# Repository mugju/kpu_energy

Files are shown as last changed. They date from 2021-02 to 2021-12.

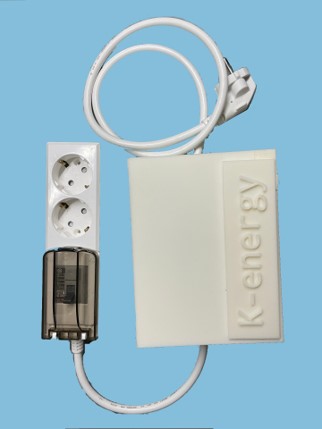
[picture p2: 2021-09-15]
Hardware/smplug.jpg

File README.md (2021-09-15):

<h1>kpu_energy</h1>
<h3>참여자 : 김동혁, 김영민, 김재현, 이영채</h3>

<h2>무엇을 위한 시스템인가요? </h2>
본 시스템은 매장 내 전자기기의 전력사용량을 모니터링하며,<br>카메라를 통한 모션인식/얼굴인식을 통해 매장 손님수를 파악하고,
<br>손님이 없을 경우 전자기기의 전원을 차단 및 출력을 조정하여 에너지 절약을 실현합니다

<h2>사용한 기술/기기 은(는) 무엇인가요?</h2>

<h2>-HW-</h2>
NodeMCU , Raspberry Pi , SCT-013 , Ir sensor ..etc<br><br>

  

<h2>-SW-</h2>
<h3>App</h3> 
<h4>Flutter</h4>




<h4>Windows Client in Pos</h4> <br>

Swing Java javafx



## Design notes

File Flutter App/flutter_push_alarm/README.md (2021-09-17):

# flutter_push_alarm

A new Flutter project.

## Getting Started

This project is a starting point for a Flutter application.

A few resources to get you started if this is your first Flutter project:

- [Lab: Write your first Flutter app](https://flutter.dev/docs/get-started/codelab)
- [Cookbook: Useful Flutter samples](https://flutter.dev/docs/cookbook)

For help getting started with Flutter, view our
[online documentation](https://flutter.dev/docs), which offers tutorials,
samples, guidance on mobile development, and a full API reference.

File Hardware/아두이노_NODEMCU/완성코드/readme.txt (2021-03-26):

오후 9:26 2021-03-26
현재 스마트 플러그 완성된 상태이며 , 웹서버와의 연동만 이루어지면 됨.

배전반 허브의 경우 현재 IR송수신 가능하며 라즈베리파이와의 연동 실험중
소스코드는 추후 추가할 예정임

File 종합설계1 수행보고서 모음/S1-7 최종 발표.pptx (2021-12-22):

## 컴퓨터 공학부 SW 캡스톤 디자인

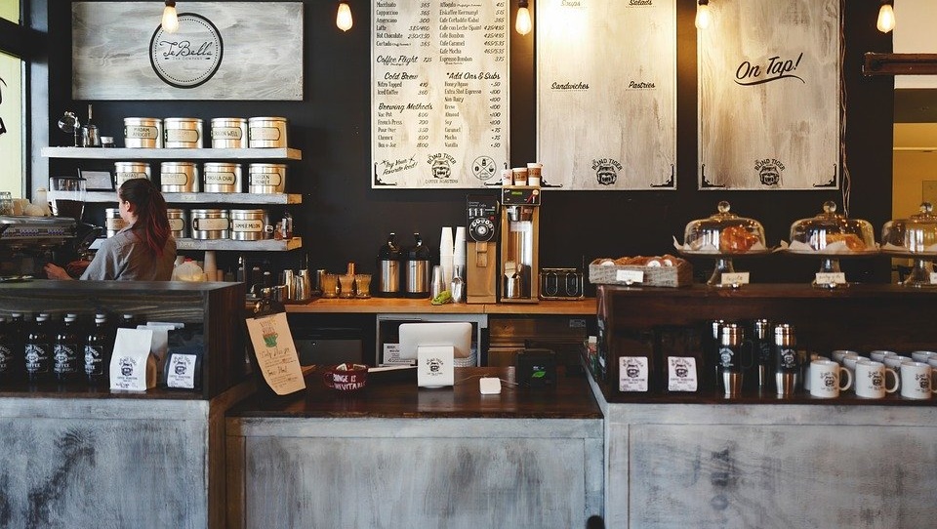
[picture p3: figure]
다방, 술집, 가게, 카페, 에스프레소, 기계, 컵, 사업, 빛, 구근, 벽, 메뉴, 보드
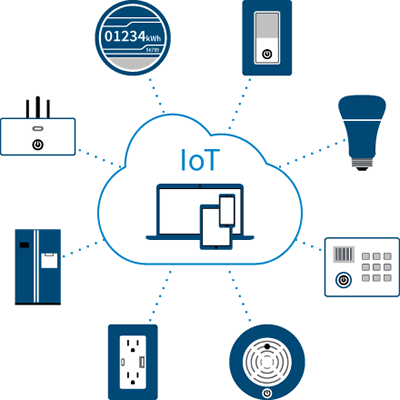
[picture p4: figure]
IoT, 스마트 홈 및 빌딩 자동화 | Power Integrations, Inc.

S1 – 7 IoT기반 에너지 매니저 시스템
기업 연계형 – Net-KTI

발표자 : 2016156003 김동혁 소프트웨어전공

지도교수 : 김영곤 교수님

팀장 : 김영민 (소프트웨어 전공) 2016156007
팀원 : 김동혁 (소프트웨어 전공) 2016156003
김재현 (소프트웨어 전공) 2016156009
이영채 (소프트웨어 전공) 2016156022

## 목차

1 작품 소개

1-1 목적
1-2 구성도

4 시연영상

2 H/W 소개

2-1 스마트 플러그 구성 / 기능
2-2 배전반 측정기 구성 / 기능
2-3 허브 구성 / 기능

3 S/W 소개

3-1 android Application
3-2 Windows app for Pos

## 작품 소개

Chapter 1

## 작품의 목적

1-1

1 개발 배경

- NetKTI와의 연계로 주제 선정
- 장시간 사용하지않는 전력기구의 대기전력제어
- 손님 유무에 따라 에너지를 제어할 수 있는 IoT 환경구성

2 작품의 목표

“매장 내 전자제품을
모니터링 및 제어할 수 있는
에너지 매니지먼트 시스템 ”

4

## 구성도

1-2

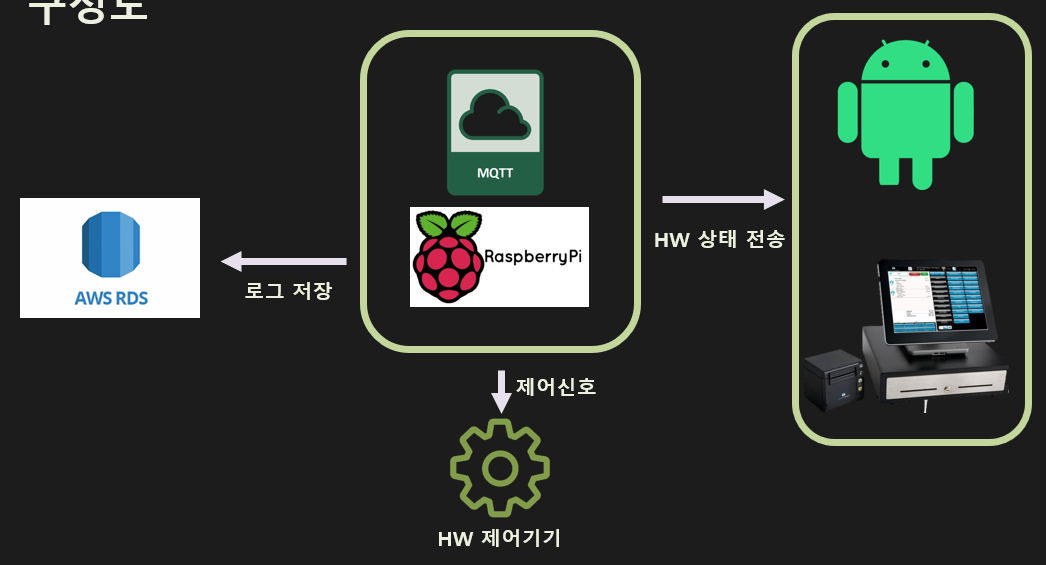
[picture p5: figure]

5

## H/W 소개

Chapter 2

## 스마트 플러그

2-1

1 스마트 플러그 전체모습

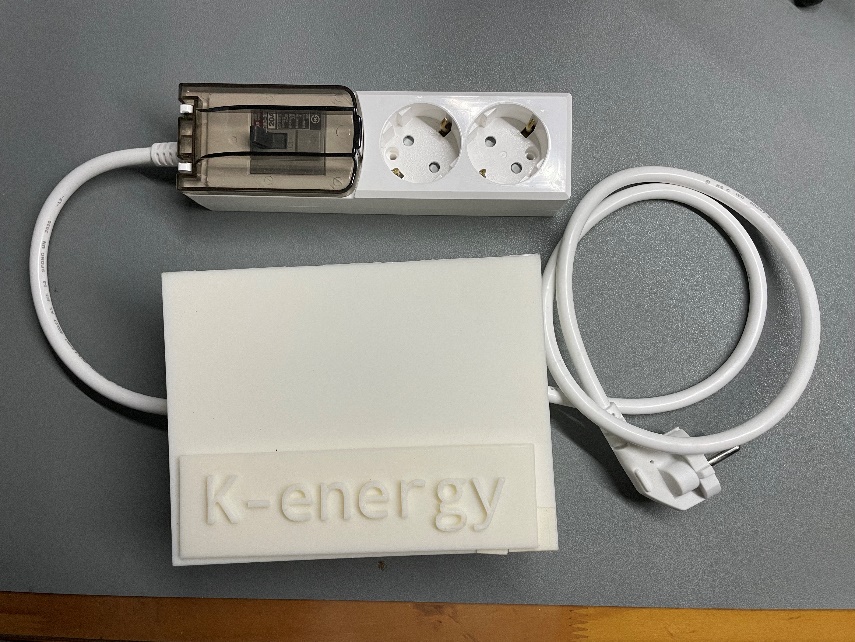
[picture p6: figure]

본문 요약

- 상세항목의 내용
- 상세항목의 내용

2 내부 구성

와이파이 MCU보드
멀티플러그
전류센서
10A 릴레이 .. etc

3 기능

사용전력 모니터링
릴레이를 통한 원격 전원 차단기능
사용 전력과 전원 on/off로그를 DB에 저장

7

## 배전반 측정기

2-2

1 배전반 측정기 전체모습

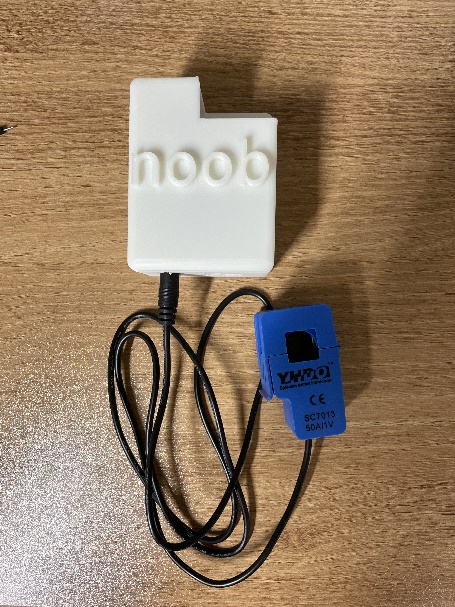
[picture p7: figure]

3 기능

사용전력 모니터링

플러그를 사용할 수 없는 기기의 전력측정을 위함
Ex) 에어컨 , 간판 (3500W 이상 혹은 지리적위치)

본문 요약

- 상세항목의 내용
- 상세항목의 내용

2 내부 구성

와이파이 MCU보드
SCT-013 (전류측정 센서)

4 특징

8

## 허브

2-3

1 허브전체모습

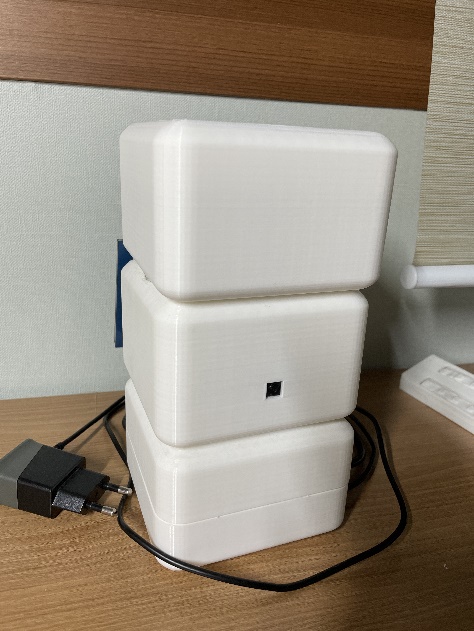
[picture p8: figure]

본문 요약

- 상세항목의 내용
- 상세항목의 내용

3 기능

HW에 제어신호를 보내는 MQTT 서버 역할 수행
모니터링 값을 사용자에게 보내주는 서버
카메라를 통한 매장 내 손님 수 파악

프라이버시를 위한 녹화기능 X
얼굴인식과 모션인식을 합하여 보다 정확한 재실인원 파악기능
외부서버가 아닌 홈 네트워크 속에서 서버를 운영하기에 속도가 빠름

2 내부 구성

라즈베리파이 3B+
5MP 카메라
Lcd모니터
LED 인디케이터
와이파이 MCU보드

4 특징

9

## S/W 소개

Chapter 3

## Android Application

3-1

1 어플리케이션 메인 스크린샷

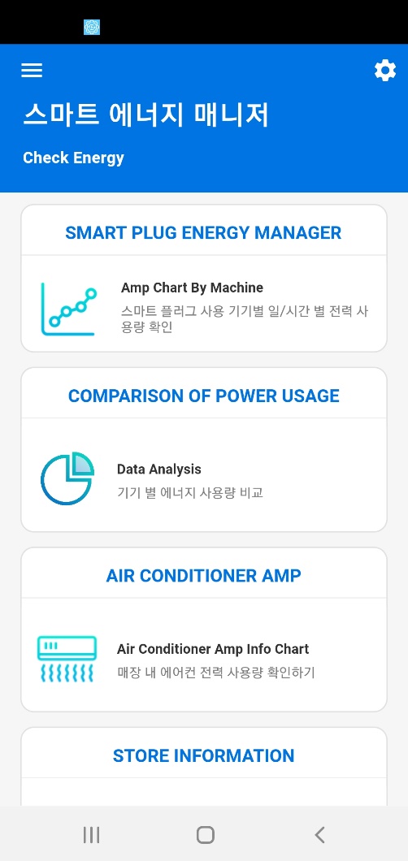
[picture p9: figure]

2 주요 기능

Smart Plug Energy Manager
→ 스마트 플러그 순간전력데이터를 zoom-in/zoom-out 그래프로 출력함

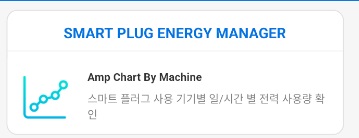
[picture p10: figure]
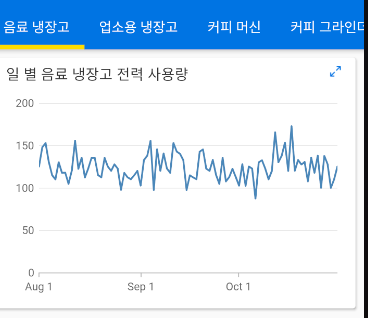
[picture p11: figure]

11

## Android Application

3-1

2 주요 기능

Comparison Of Power User
→ 해당 데이터로 다양한 각도에서 그래프 정보 출력
→ 기기 별 에너지 사용량 비교 그래프 출력

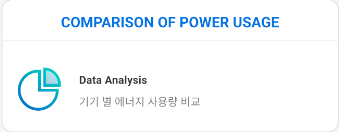
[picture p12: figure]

기기원격제어
- smart plug 제어 가능
- 스마트 플러그 on/off시 푸시 알림 수신
- 재실 인원 유무 파악
- 스마트플러그, 배전반 순간/누적 전력 표시

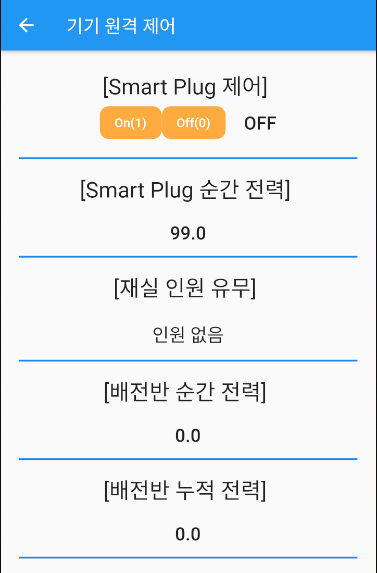
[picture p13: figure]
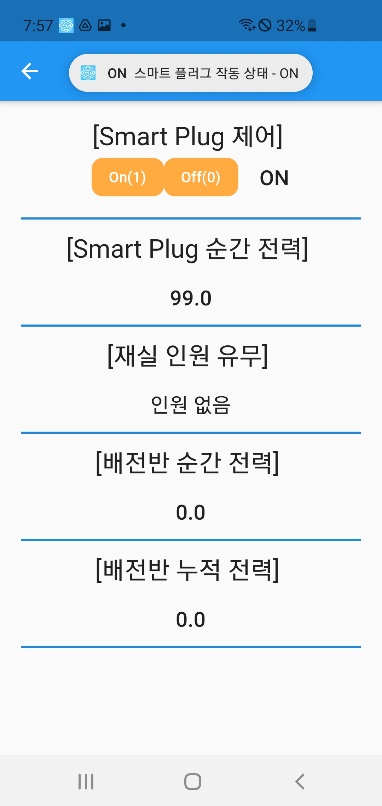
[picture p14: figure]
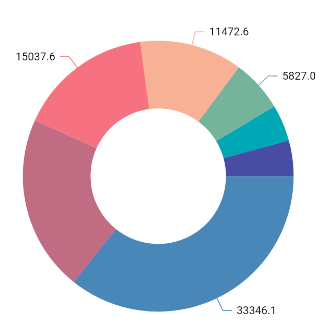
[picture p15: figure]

12

## Client program in Pos

3-2

1 클라이언트 프로그램 스크린샷

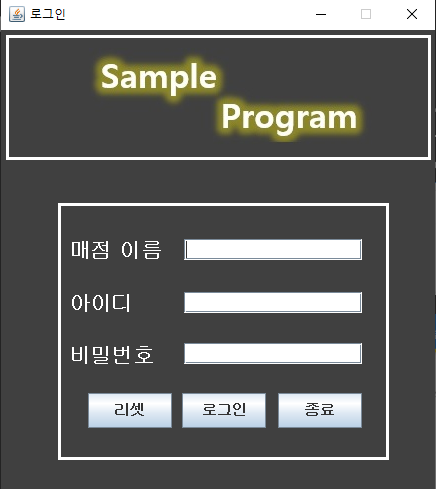
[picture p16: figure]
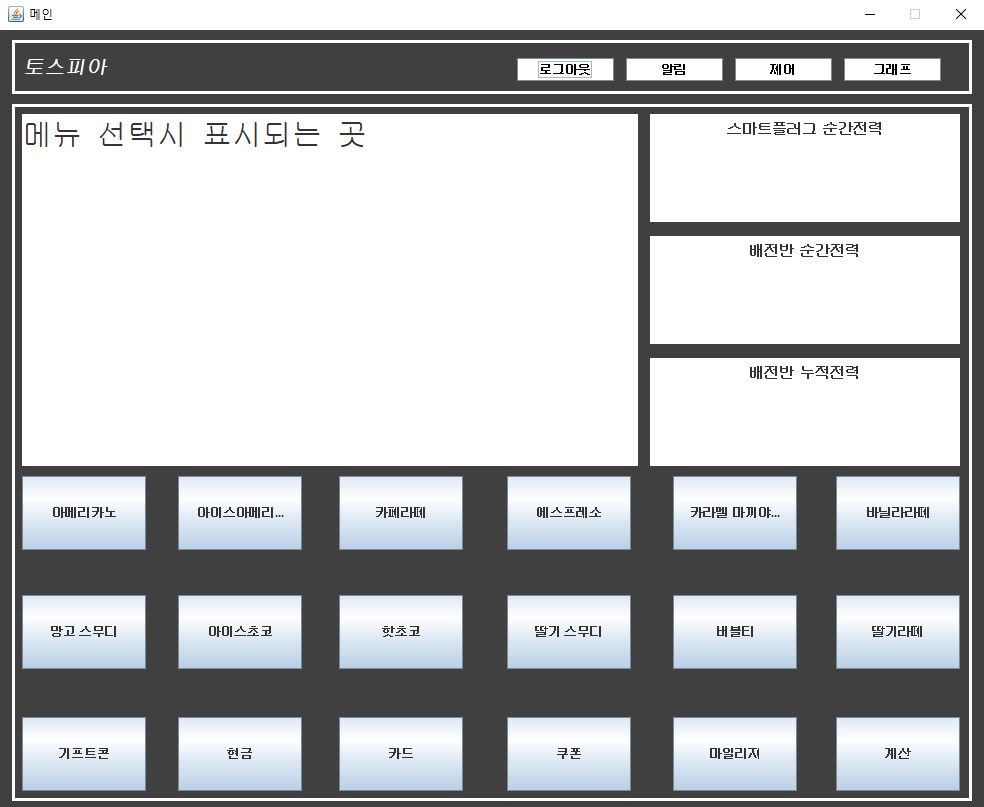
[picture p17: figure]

13

## Client program in Pos

3-2

2 기능

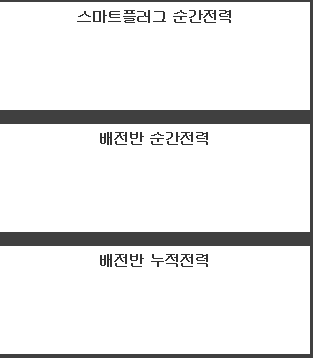
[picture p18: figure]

전력값 출력
→ 스마트 플러그와 배전반에서 측정한 순간 전력과 누적전력을 화면에 실시간으로 출력

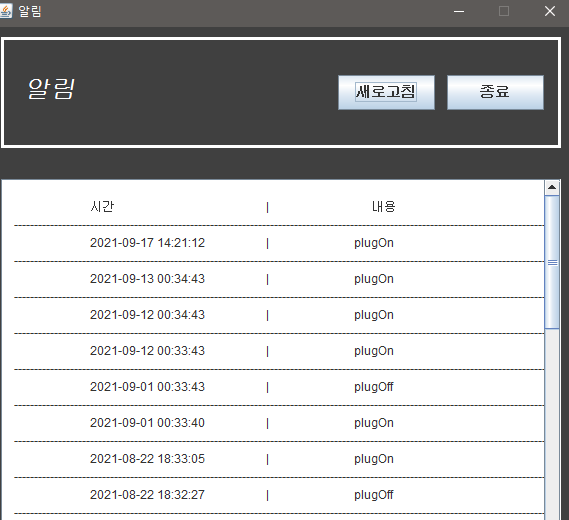
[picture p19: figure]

전원 기록 알림
→ 프로그램이 종료되어 있을 때 푸시 알림을 받을 수 없으므로 DB에 저장된 스마트 플러그의 활동을 보여줌

14

## Client program in Pos

3-2

2 기능

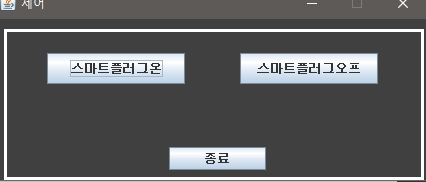
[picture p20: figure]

기기원격제어
- 스마트 플러그 제어 가능
- 원격제어시 팝업을 통한 알림

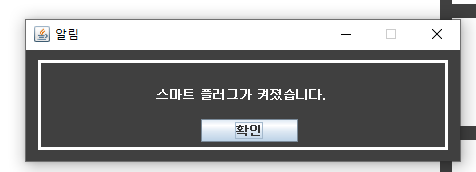
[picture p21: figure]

그래프 출력
- 제품별, 시간/일/월을 기준으로 전력 사용량을 그래프로 표현

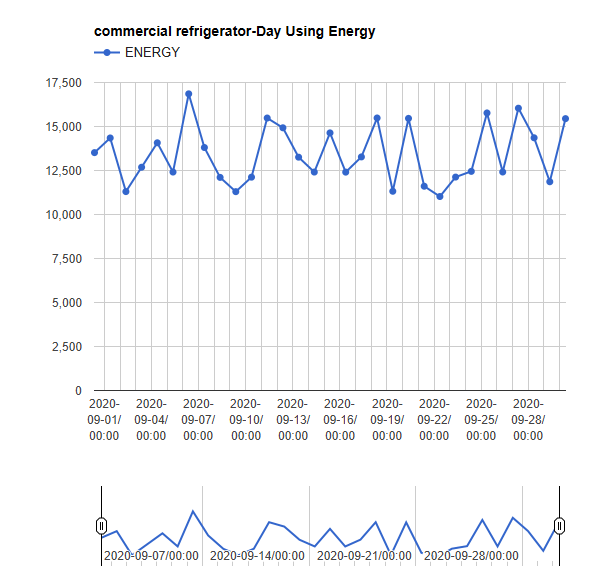
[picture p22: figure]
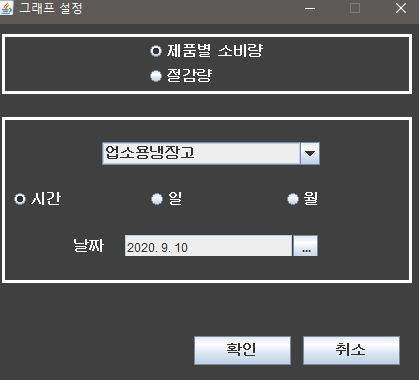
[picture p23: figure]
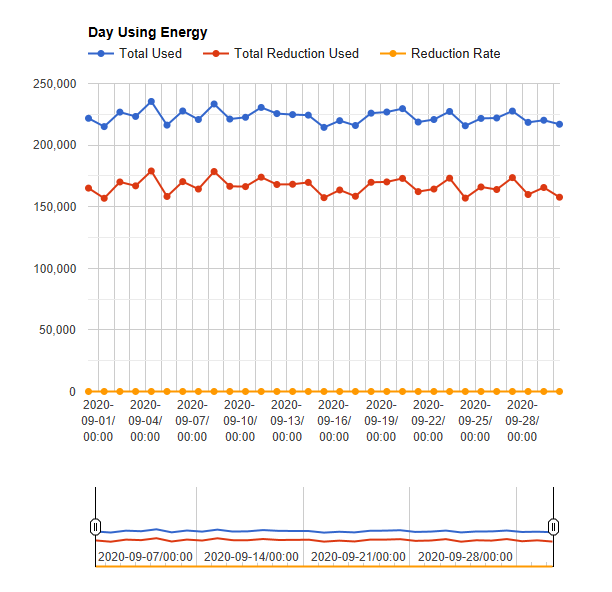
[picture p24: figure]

15

## 시연 영상

Chapter 4

## 감사합니다.

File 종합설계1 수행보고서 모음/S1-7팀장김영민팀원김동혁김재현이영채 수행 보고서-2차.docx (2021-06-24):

종합설계 프로젝트 수행 보고

프로젝트명 | IoT기반 에너지 매니저시스템
팀번호 | S1-7
문서제목 | 수행계획서( O ) 2차발표 중간보고서( ) 3차발표 중간보고서( ) 최종결과보고서( )

기업연계 : Net-KTI

2021.03.08

팀원 : 김영민(팀장)

김동혁

김재현

이영채

지도교수 : 김영곤 교수님 (인)

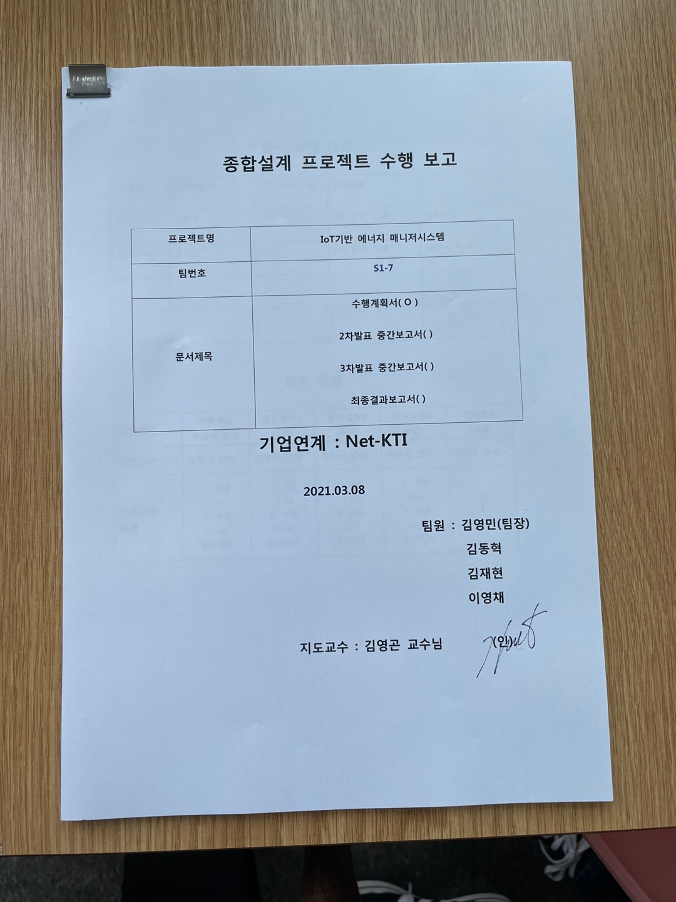
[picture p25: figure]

문서 수정 내역

작성일 | 대표작성자 | 버전(Revision) | 수정내용
2021.2.14 | 김동혁 | 1.0 | 1차 발표 자료 | 최초작성
2021.03.01 | 김영민 | 2.0 | 2차 발표 자료 | 설계서 추가

문서 구성

진행단계 | 프로젝트 계획서 발표 | 중간발표1 (3월) | 중간발표2 (5월) | 학기말발표 (6월) | 최종발표 (10월)
기본양식 | 계획서 양식 | 계획서 양식 | 계획서 양식 | 계획서 양식 | 계획서 양식
포함되는 내용 | Ⅰ. 서론 (1~6) Ⅱ. 본론 (1~3) 참고자료 | Ⅰ. 서론 (1~6) Ⅱ. 본론 (1~4) 참고자료 | Ⅰ. 서론 (1~6) Ⅱ. 본론 (1~5) 참고자료 | Ⅰ. 서론 (1~6) Ⅱ. 본론 (1~7) 참고자료 | I II III

이 문서는 한국산업기술대학교 컴퓨터공학부의

“종합설계”교과목에서 프로젝트

“IoT기반 에너지 매니저시스템”을 수행하는

(S1-7, 김영민,김재현,김동혁,이영채)들이 작성한 것으로 사용하기 위해서는 팀원들의 허락이 필요합니다.

기업 질문사항 및 답변

기업 담당자: 김태형

질문 번호 | PPT page | 질문내용 | 팀에서 고려사항 | 답변
1 | 3p | 주제의 적용을 매장으로 선택하고 진행하고 있는데 실제로 사용되고 있는 공간이 있는지? 있다면 어떤 공간인지 알려주실 수 있나요 | 저희 팀에서는 학교 내 에 있는 맘스터치와 같은 프랜차이즈 매장에 도입하는 것을 생각하고 있습니다. | 인건비 부담으로 인해 무인화가 트렌드가 되어 카페 / 무인독서실 / 대형 프랜차이즈 등 다수의 업종에 적용되어 있습니다.
2 | | 이런 시스템을 적용시킬 수 있는 장소 (1번에서 고려해주신 장소)의 샘플데이터를 받을 수 있나요? (전력, 온도 등등..) | 일단 저희가 전력데이터를 수집하기위해 접촉/ 비접촉 전류센서를 사용하고 있고, 온 습도, 모션인식을 통해 손님수를 측정하는데 더 고려할 요소가 있는지 궁금합니다. | 샘플 데이터는 보안 및 개인정보문제로 외부 변환이 안되어 제공이 어렵습니다. 재실감지 센서라고 레이더센서/마이크로파 등을 이용하여 입출입 인원 파악이 가능한 센서가 있으니 찾아보시기 바랍니다.
3 | | 전력수집 및 제어 대상으로 혹시 저희가 설정한 것 이외에 더 추가할 만한 것을 추천해 주실 수 있을까요? | 저희가 고려한 바는 냉난방기구, 조명, 스크린 정도를 고려하고 있는데 | 온도센서 / 스마트플러그를 활용하면 온냉장 시설의 항온 유지 기능이 구현 가능합니다. (수족관 등 온도변화에 민감한 동식물 관리) - 산소포화도 센서 및 발생기를 추가하여 일정한 환경 구성 가능

표 1

# 1. 서론

주요 내용 | 1-1. 작품선정 배경 및 기존 기술 분석 1-2. 프로젝트 개발 목표 1-3. 팀 역할 분담 1-4. 개발 일정 1-5. 개발 환경

## 1-1. 작품선정 배경 및 기존 기술 분석

1) 작품선정 배경

-에너지를 효율적으로 관리하기 위한 시스템의 필요

-한창 떠오르는 4차 산업혁명의 기술 적용에 적합

이에 따라 기존 유사 기술들을 분석한 결과,

관련 연구 및 사례 | 개선점
스마트빌딩 통합관리·E절감솔루션 | - 관련 전문 지식을 보유하지 않은 일반 사용자도 이용하기 편하도록 인터페이스를 구현
오 파워 | - IoT를 사용하여 에너지 장치 각각의 데이터를 수집하고 제어한다.
글로벌 스마트시티(스마트 매장 에너지 관리) | - 실내 온도, 밀집도와 같은 환경 요소들도 파악하여 서비스 제공 - 빅데이터를 사용하여 적절한 에너지 사용 방법 알림

와 같은 개선점을 찾을 수 있었음.

이에 따른 구체적 해결방안으로

에너지 사용량을 파악하기 위해 에너지 사용량을 시각화 해야함.

- 사용량을 그래프를 사용하여 사용자가 알아보기 쉽게 제공.

- 지정한 사용량 초과 및 비정상적인 사용량 인식 시에 사용자에게 알림 제공

각 에너지 사용량을 측정하는 센서 데이터들을 모아 딥러닝을 통해 자동적인 관리 시스템을 구축한다.

- 각 요인에 따라 자동적으로 기기들을 제어하고, 수동적인 제어 역시 스마트폰이나, PC로 제어 가능하다.

- 제어된 로그들은 사용자에게 앱이나 웹의 형태로 제공된다.

## 1-2 프로젝트 개발 목표

1) 연구 및 개발 목표

IoT를 사용하여 다양한 에너지 사용량을 측정하고, 측정된 데이터를 빅데이터를 통해 분석하여 에너지를 효율적으로 사용하도록 사용자에게 알맞은 사용방법을 추천할 수 있도록 한다. 또한 인공지능에 의해 각종 에너지를 통제하고 사용자가 원격으로도 제어가 가능하도록 한다.

2) 기능정의
- 사용자에게 에너지 사용량을 시각화하여 보여준다.
- 에너지 소비 솔루션을 인공지능을 통해 제공한다.
- 에너지 소비 피크 시간에 대한 정보를 인공지능을 통해 분석하여 제공한다.
- 절감 효과에 대한 결과 데이터를 제공한다.
- 에너지는 전기, 온도로 정의한다.
- 사용량에 대한 기준을 정하고, 초과했을 때 알림 기능을 제공한다.
- 웹으로 모니터링 시스템을 제공한다.
- 모든 에너지는 스마트폰 어플리케이션을 통해 제어가 가능하다.
- 에너지 소비에 대한 제어는 인공지능과 사용자에 의해 제어된다.
- 날씨, 유동인구, 시간 데이터에 대한 정보를 사용하여 데이터를 분석한다.
- 에너지 데이터는 외부 서버 데이터베이스에 저장된다.
- 음성 인식을 통해 제어가 가능하도록 한다.

## 1-3 팀 역할 분담

| 김재현 | 이영채 | 김영민 | 김동혁
자료수집 | - HTML, JSP - Android Studio | - AWS RDS - 영상 처리 | - Google colab - 머신 러닝 모델 | - 라즈베리파이 - Atmega, 센서
설 계 | - 정보 웹 페이지 - 앱 | - 데이터 베이스 설계 - 모션 인식 개발 | - 머신 러닝 모델 적용 | - 라즈베리파이와 Atmega 연동
구 현 | - 웹페이지에 정보 표시 - 앱으로도 호환 | - 데이터 베이스 구축하여 데이터 관리 - 카메라를 이용한 모션 인식 | - 머신 러닝을 통해 결과 예측 | - 라즈베리파이에서 수집한 데이터 전송 - Atmega를 이용한 데이터 수집
테스트 | - 머신 러닝 - 예측 결과 - 웹 페이지, 앱 연동 - 라즈베리파이, Atmega 연동 및 데이터 수집

## 1-4 개발 일정

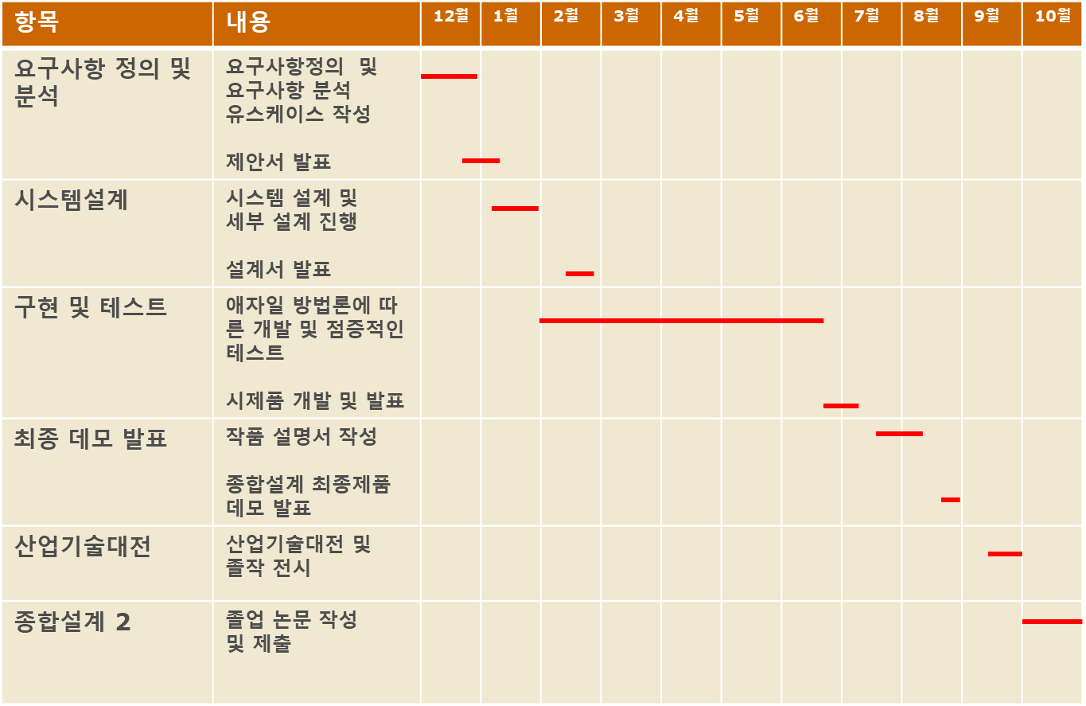
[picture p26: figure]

## 1-5 개발 환경

스마트 플러그 | NODEMCU | Esp8266 탑재. 인터넷 접속과 데이터 수집을 수행
| ACS-712 | 교류전류데이터 수집
| DHT-22 | 온습도 측정
| 5V relay | 5v 구동 릴레이, 전자기기 전원제어
| AC-DC컨버터 | 교류전원을 사용하여 보드, 센서를 구동

허브 | Arduino uno | 센서데이터 수집용(analog)
| SCT-013 | 비접촉 전류센서 (배전반 사용)
| Raspberry 3b+ | 영상처리, 아두이노 전원제공, 인터넷 접속
| Pi camera | 손님인식용 카메라
| 적외선 송,수신 센서 | 리모콘의 신호를 복제하여 기기제어

S/W | 서버 | Apache Tomcat 9.0 / Ubuntu 18.0.4 LTS
| DB | RDS for MySQL 8.0
| 머신 러닝 | Google Colaboratory
| 시각화 | Grafana
| 모션 인식 | OpenCV

# 2. 본론

주요 내용 | 2-1. 개발 내용 1) 환경 데이터 수집 2) 스마트 플러그 3) 제어 허브(배전반 측정용) 4) 머신 러닝 5) 웹 6) 데이터 베이스 2-2. 문제 및 해결 방안 2-3. 수행 시나리오 1) 구성도 2) 데이터 수집 시나리오 3) 데이터 저장 & 머신 러닝 시나리오 4) 사용자 인터페이스 시나리오 5) 제어 시나리오 2-4. 상세 설계 1) 유스케이스 다이어그램 2) 클래스 다이어그램 2-1) Display 2-2) MachineLearning 2-3) Sensor 1) PeopleRecogSensor 2) ampSensor 3) DHTSensor 2-4) Control 1) IRControl 1-1) AirControl 1-2) MonitorControl 2) PlugControl 3) GUI 화면 설계 3-1) 로그인 화면 3-2) 메인 화면(전체 모니터링) 3-3) 실시간 기상데이터 3-4) 사용비율 비교 3-5) 에너지 사용 예측 3-6) 기간별 사용량 3-7) 에너지 제어 3-8) 문의

## 2-1. 개발 내용

1) 환경 데이터 수집


2) 스마트 플러그


3) 제어 허브 (배전반 측정용)


4) 머신 러닝


5) 웹


6) 데이터 베이스


## 2-2 문제 및 해결 방안

문제 | 시스템을 사용하기 위한 인터페이스는 어떻게 구현할 것인가
해결 방안 | 스프링 프레임워크를 이용하여 웹을 구현하고 Apache Tomcat을 이용해 서버를 운영한다. 웹은 사용자에게 실제 에너지 사용량, 예상 에너지 사용량, 에너지 절감량, 기기 제어 등의 기능을 제공한다.

문제 | 전력데이터를 어떻게 수집할 것인가?
해결 방안 | 전력을 바로 구할수 있는 센서는 존재하지 않았고 전류센서로 전압을 곱해 전력을 구할 수밖에 없었다. 다만 여기서 일반적인 전류센서의 경우 접촉 방식으로 전선을 단선하여 측정하는 방식이었는데 저 전류의 경우 크게 위험하지않지만 에어컨이나 높은 전류가 흐르는 제품의 경우 단선하여 연결하는데에 큰 부담이 되었다. 이에따라 조사중 비접촉 전류센서인 SCT 013 제품을 찾아 배전반에 매설하는 방식으로 전력을 측정하도록 하였다.

문제 | 제품을 어떻게 제어할 것인가?
해결 방안 | 단순한 제품들이라면 그저 전원을 끊고 연결하기만하면 충분하지만 전선이 직접적으로 연결되어있지않은 즉, 비접촉 전류센서를 이용하는 제품의 경우 제어가 어려웠다. 에어컨이 가장 큰 경우였는데 고민중 IR(적외선) 신호를 이용해 기존 리모콘의 적외선 신호를 복제하여 원거리에서 풍량, 온도등을 제어하는 방법을 고안했다. 이 방법은 단순하게 에어컨 뿐만 아니라 전선이 매설되어있는 전자기기 (프로젝터등) 과 같은 기기의 제어에도 효과적일 것이라 생각한다.

문제 | 사람 인식을 함에 있어, 정면 외의 모습은 인식이 불가한 문제를 어떻게 해결할 것인가?
해결 방안 | 사람의 뒷 모습이나 옆 모습, 앉아있는 모습까지 학습시키는 것에 무리가 있다고 판단하여 움직임을 감지하는 방법으로 변경하기로 했다. 데이터베이스에 전송할 때는 5분 내에 움직임이 감지되면 1을 전송하여주고, 이외에는 0을 전송하도록 했다.

문제 | 머신러닝을 어떤 분야에 적용할 것인가?
해결 방안 | 초기에 대략적인 구상으로만 머신러닝을 해당 졸업 작품에 접목하여 적용 범위가 불명확했었다. 팀원들과 충분히 토의한 결과 수집한 데이터를 통해 미래의 전력 사용량을 예측하는 분야에서 머신러닝을 접목시킬 수 있다고 결론을 도출하였다. 현재 딥러닝 모델중 LSTM 모델과 Facebook에서 개발한 Prophet 모델을 사용 모델로 고려중으고, 현재 수집 중인 데이터에 대해 더 효율적인 모델을 찾기 위해 노력하겠다.

## 2-3 수행 시나리오

1) 구성도


2) 데이터 수집 시나리오
      1. 매장 내 전력사용량을 전류센서를 통해 수집한다.


      2. 매장 내 실내온습도를 DHT22 센서를 통해 수집한다.
      3. 매장 내 카메라를 이용하여 매장내 손님수를 분석하여 라즈베리파이에 유선으로 저장한다.
3) 시스템 수행 시나리오 – 데이터 저장 & 머신러닝


1. 라즈베리파이에서 센서데이터를 데이터베이스로wifi를 통해 전송한다.
2. 데이터베이스에서는 구글 클라우드로 데이터를 제공해준다.
3. 기상청으로부터 외부 날씨 데이터를 API를 통해 받아온다.
4. 수집한 데이터들을 통한 머신러닝을 통해 예측전력값을 구한다.
5. 예측데이터를 데이터 베이스에 저장한다.
4) 시스템 수행 시나리오 – 사용자 인터페이스


      1. 데이터베이스에 저장된 데이터를 시각화하여 웹서버로 전송한다.
      2. 웹서버는 사용자에게 인터페이스를 제공한다.
5) 시스템 수행 시나리오 – 제어


      1. 사용자 인터페이스에서 제어명령을 내린다.
      2. 해당 명령은 웹서버를 거쳐 원격제어 모듈로 전송된다.
      3. IR신호, 및 릴레이를 사용하여 전열기구, 전등, 플러그, 모니터 등을 제어한다.

## 2-4 상세 설계

1) 유스케이스 다이어그램


2) 클래스 다이어그램


2-1) Display

설명 | 웹에서 데이터 베이스의 정보를 이용하여 시간별 예측 전력 사용량, 현재 전력 사용량, 기기를 제어해 절감된 전력량을 시각화하여 사용자한테 제공한다.
메서드 | public showChart(self, object):void | 데이터를 시각화하여 사용자한테 제공한다.
| public getData(String,datetime) : object | 데이터 베이스에서 현재 사용중인 데이터를 가져온다.
| public getPredictData(String): float[][] | 데이터 베이스에서 머신러닝을 통해 구한 예측 전력값을 가져온다.

2-2) MachineLearning

설명 | Google Colaboratory를 통해 데이터 베이스에 저장된 현재 사용전력, 시간, 온습도, 인구 밀도를 활용하여 이후의 예측 소비 전력을 계산한다.
메서드 | public getData(String, datetime, datetime) : object | 데이터 베이스에서 머신러닝에 활용할 데이터를 가져온다.
| public AnalyzeData(object): float | 데이터를 머신러닝을 통해 분석하여 예측값을 도출한다.
| public sendData(String, datetime, float) : int | 머신러닝을 통해 도출한 값을 데이터베이스로 보낸다.

2-3) Sensor

설명 | 카메라, 온습도 센서, 조명 센서를 추상화한 클래스. 각각의 센서 클래스들이 상속하여 사용한다.
메서드 | public collectData(void) : void | 각 센서로부터 데이터를 gpio및 아날로그 핀을 통해 수집한다.
| public sendData(void) : void | 수집된 데이터를 사전에 정의해둔 sql서버로 전송한다.
| public setUpDatetime(void) : int | 아두이노 보드의 wifi연결을 통해 NTP서버로부터 시간을 받아와 동기화 한다.

1) PeopleRecogSensor

설명 | 카메라를 이용해 매장내의 손님수를 API를 사용하여 인식한다.
메서드 | public collectData(void) : void | 각 센서로부터 데이터를 gpio및 아날로그 핀을 통해 수집한다.

2) ampSensor

설명 | ACS712센서 및 SCT013센서를 이용해 전류를 측정한다.
메서드 | public sendData(int, datetime, float) : int | 전류센서의 데이터를 데이터베이스 로 현재 시간과 함꼐 전송한다.
| public collectData(int) : int | 전류데이터를 센서로부터 수집한다.

3) DHTSensor

설명 | DHT22 센서를 이용하여 매장내의 온/습도를 측정한다.
메서드 | public sendData(int, datetime, int, int) : int | 온습도 센서의 데이터를 데이터베이스로 전송한다.
| public collectData(int) : int[] | 온습도 데이터를 측정하고 이에 대한 결과를 배열로 반환한다.

2-4) Control

설명 | 자체 제작한 스마트 플러그, 배전반을 조작하는 인터페이스 인터페이스를 이용하여 각각의 컨트롤러에 연결된 기기를 제어한다.
메서드 | public deviceOn(int): int | 디바이스의 전원을 연결된 릴레이를 통해 켜는 함수이다.
| public deviceOff(int): int | 디바이스의 전원을 연결된 릴레이를 통해 끄는 함수이다.

1) IRControl

설명 | 적외선 리모컨을 사용하는 제품의 제어를 담당하는 클래스이다. AirControl과 MonitorControl에 상속을 해준다.
메서드 | public copySignal(void): ulong | 리모컨의 IR신호를 시스템에 저장받는 함수이다.

1-1) AirControl

설명 | IRControl에서 상속을 받아 바람 세기와 온도를 조절하는 클래스이다.
메서드 | public controlTemp(ulong) : int | 냉난방기의 온도를 조절하는 함수이다.
| public controlPower(ulong) : int | 냉난방기의 바람 세기를 조절을 하는 함수이다.

1-2) MonitorControl

설명 | IRControl에서 상속을 받아 TV를 제어하는 클래스이다.
메서드 | public deviceTVOn(ulong): void | TV의 전원을 켜는 함수이다.
| public deviceTVOff(ulong): void | TV의 전원을 끄는 함수이다.

2) PlugControl

설명 | 스마트 플러그의 제어를 하는 클래스이다. Control interface를 사용한다.
메서드 | public relayControl(void): int | 릴레이를 통해 스마트 플러그의 장비를 제어한다.

2-5) DB_interface

설명 | AWS RDS를 사용할 수 있는 데이터베이스 인터페이스. 서버 주소, 사용자 정보를 이용하여 데이터 베이스를 사용한다.
메서드 | public loginServer(IPAddress, char, char): int | 데이터 베이스에 매장별 접속을 할 수 있게 해주는 함수이다.
| public addNewStore() : int | 데이터베이스에 새로운관리대상 매장을 추가하는 메소드

3) GUI 화면 설계

웹 화면설계

  3-1) 로그인 화면


  3-2) 메인화면(전체 모니터링)


  3-3) 실시간 기상데이터


  3-4) 사용비율 비교


  3-5) 에너지 사용 예측


  3-6) 기간별 사용량


  3-7) 에너지 제어


  3-8) 문의


상세 설명

- 사용자는 매장에 부여된 아이디와 비밀번호를 통해 웹으로 접근을 한다.
- 로그인 후 전체적인 에너지의 모니터링을 하는 메인 페이지가 출력된다.
- 왼쪽의 네비게이션 바를 통해 원하는 메뉴로 접근한다.
- 각각의 메뉴를 통해 사용자에게 유용한 정보를 제공한다.
- 제어 메뉴에서는 사용자가 전자기기를 제어할 수 있도록 한다.

# 필요 기술 및 참고 문헌

## 1) 관련 연구 사례

- 2017년 차세대에너지연구소 고유과제 결과 보고서

https://scienceon.kisti.re.kr/commons/util/originalView.do?cn=TRKO201800035622&dbt=TRKO&rn=

- KT meg

http://www.enet.or.kr/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 pp. 2-18

- 빌딩 에너지 관리 시스템의 기술 및 표준화 동향

https://www.google.co.kr/url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 (https://www.google.co.kr/url?rct=j&q=&esrc=s&cd=)

- 오파워

https://www.hellot.net/new_hellot/magazine/magazine_read.html?code=205&sub=001&idx=44952&page=1&list=all

- 글로벌 스마트 시티

http://www.k-smartcity.kr/service1/service07.php

## 2) 사용 라이브러리

- 아두이노 DHT 라이브러리 https://github.com/adafruit/DHT-sensor-library
- ESP8266 인터넷시간 알아보는 라이브러리 https://github.com/mcxiaoke/ESPDateTime
- Mysql connector 척벨 (https://github.com/ChuckBell/MySQL_Connector_Arduino)
- SCT-013 사용관련 회로참고 https://learn.openenergymonitor.org/electricity-monitoring/ct-sensors/how-to-build-an-arduino-energy-monitor-measuring-current-only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

## 3) 화면 설계

- 라임 ICT http://limeict.co.kr/product_cb.html

## 4) 머신 러닝

- 시계열 예측 https://www.tensorflow.org/tutorials/structured_data/time_series
- Prophet https://facebook.github.io/prophet/docs/quick_start.html#python-api
- LSTM https://brunch.co.kr/@chris-song/9

## 5) Google Cloud Platform

- 역 지오 코딩 https://cloud.google.com/solutions/reverse-geocoding-geolocation-telemetry-cloud-maps-api?hl=ko
- IP Geolocation API https://geo.ipify.org/

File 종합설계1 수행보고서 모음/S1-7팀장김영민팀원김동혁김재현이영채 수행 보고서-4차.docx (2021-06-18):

종합설계 프로젝트 수행 보고

프로젝트명 | IoT기반 에너지 매니저시스템
팀번호 | S1-7
문서제목 | 수행계획서( O ) 2차발표 중간보고서( O ) 3차발표 중간보고서( O ) 4차발표 중간보고서( O ) 최종결과보고서( )

기업연계 : Net-KTI

기업 담당자 : 김태형

참고 매장: 산기대 토스피아(*별첨2 첨부)

2021.06.17

팀원 : 김영민(팀장)

김동혁

김재현

이영채

지도교수 : 김영곤 교수님 (인)


문서 수정 내역

작성일 | 대표작성자 | 버전(Revision) | 수정내용
2021.2.14 | 김동혁 | 1.0 | 1차 발표 자료 | 최초작성
2021.03.01 | 김영민 | 2.0 | 2차 발표 자료 | 설계서 추가
2021.05.06 | 김재현 | 3.0 | 3차 발표 자료 | Prototype 구현
2021.06.17 | 이영채 | 4.0 | 4차 발표 자료 | 코딩&테스트결과

문서 구성

진행단계 | 프로젝트 계획서 발표 | 중간발표1 (3월) | 중간발표2 (5월) | 학기말발표 (6월) | 최종발표 (10월)
기본양식 | 계획서 양식 | 계획서 양식 | 계획서 양식 | 계획서 양식 | 계획서 양식
포함되는 내용 | Ⅰ. 서론 (1~6) Ⅱ. 본론 (1~3) 참고자료 | Ⅰ. 서론 (1~6) Ⅱ. 본론 (1~4) 참고자료 | Ⅰ. 서론 (1~6) Ⅱ. 본론 (1~5) 참고자료 | Ⅰ. 서론 (1~6) Ⅱ. 본론 (1~7) 참고자료 | I II III

이 문서는 한국산업기술대학교 컴퓨터공학부의

“종합설계”교과목에서 프로젝트

“IoT기반 에너지 매니저시스템”을 수행하는

(S1-7, 김영민,김재현,김동혁,이영채)들이 작성한 것으로 사용하기 위해서는 팀원들의 허락이 필요합니다.

기업 질문사항 및 답변

기업 담당자: 김태형

질문 번호 | PPT page | 질문내용 | 팀에서 고려사항 | 답변
1 | 3p | 주제의 적용을 매장으로 선택하고 진행하고 있는데 실제로 사용되고 있는 공간이 있는지? 있다면 어떤 공간인지 알려주실 수 있나요 | 저희 팀에서는 학교 내 에 있는 맘스터치와 같은 프랜차이즈 매장에 도입하는 것을 생각하고 있습니다. | 인건비 부담으로 인해 무인화가 트렌드가 되어 카페 / 무인독서실 / 대형 프랜차이즈 등 다수의 업종에 적용되어 있습니다.
2 | | 이런 시스템을 적용시킬 수 있는 장소 (1번에서 고려해주신 장소)의 샘플데이터를 받을 수 있나요? (전력, 온도 등등..) | 일단 저희가 전력데이터를 수집하기위해 접촉/ 비접촉 전류센서를 사용하고 있고, 온 습도, 모션인식을 통해 손님수를 측정하는데 더 고려할 요소가 있는지 궁금합니다. | 샘플 데이터는 보안 및 개인정보문제로 외부 변환이 안되어 제공이 어렵습니다. 재실감지 센서라고 레이더센서/마이크로파 등을 이용하여 입출입 인원 파악이 가능한 센서가 있으니 찾아보시기 바랍니다.
3 | | 전력수집 및 제어 대상으로 혹시 저희가 설정한 것 이외에 더 추가할 만한 것을 추천해 주실 수 있을까요? | 저희가 고려한 바는 냉난방기구, 조명, 스크린 정도를 고려하고 있는데 | 온도센서 / 스마트플러그를 활용하면 온냉장 시설의 항온 유지 기능이 구현 가능합니다. (수족관 등 온도변화에 민감한 동식물 관리) - 산소포화도 센서 및 발생기를 추가하여 일정한 환경 구성 가능
4 | | 원래는 머신러닝 분야는 최근 데이터를 바탕으로 미래의 전력을 예측하는 알고리즘인데, 토론을 하다보니 이 기능이 매장에서는 사용량이 비교적 일정할 것 같다고 생각되어서 굳이 머신러닝을 사용하지 않아도 될것 같다는 생각이 들었습니다. 혹시 기존 시스템에서는 주로 어떤 분야에서 머신러닝을 활용하고 있는지 궁금합니다. | 현재 에너지 메니저 시스템을 구현하기 위해 수집하는 데이터의 종류는 온습도, 외부 온습도, 수집되는 전류량, 재실 인원 유무가 있습니다. | 전력/온습도를 측정하고 빅데이터화 하여 머신러닝을 적용하는 최종목표는 장비의 이상을 사전 감지하는 예지보전 입니다. 실 구축 현장에서도 아직 완전히 적용은 되지 않았으나, 각각의 장비별 개별 사용 전력/주변 온습도 변화를 실시간 측정하고, 향후 장비 고장/누전/화재 등 이상상황 발생 시, 이를 머신러닝에 적용하여 유사한 상황에서 앞으로 발생할 수 있는 이상상황 알람 (장비 점검 권고 등) 을 사전에 파악하여 관리자에게 제공하려고 하고 있습니다.
| | 추가적으로 가능하거나, 혹은 더 개선할만한 머신러닝할 분야를 어떤 부분에서 적용하는 것이 좋을지알려주시면 감사하겠습니다. | | 지금 진행되고 있는 케이스는 1. 냉장고 냉장 모터 고장 (온도/전력) 2. 주유소 주유기/세차장 등이 있으며, 아직은 온도/전력량 계측과 고장/누전/화재 등 과의 명확한 상관관계는 밝혀지지 않았으나, 이러한 데이터가 장시간 수집되었을 때 향후 사전에 예측이 가능한 특성이 있을 가능성이 있어, 꾸준히 데이터를 수집하고 있습니다. (산업용 IoT에서는 좀 더 세분화 되어, 각 포인트별 진동/전류량/모터RPM 등이 수집되고 있습니다.)

표 1

# 1. 서론

주요 내용 | 1-1. 작품선정 배경 및 기존 기술 분석 1-2. 프로젝트 개발 목표 1-3. 팀 역할 분담 1-4. 개발 일정 1-5. 개발 환경

## 1-1. 작품선정 배경 및 기존 기술 분석

1) 작품선정 배경

-에너지를 효율적으로 관리하기 위한 시스템의 필요

-한창 떠오르는 4차 산업혁명의 기술 적용에 적합

이에 따라 기존 유사 기술들을 분석한 결과,

관련 연구 및 사례 | 개선점
스마트빌딩 통합관리·E절감솔루션 | - 관련 전문 지식을 보유하지 않은 일반 사용자도 이용하기 편하도록 인터페이스를 구현
오 파워 | - IoT를 사용하여 에너지 장치 각각의 데이터를 수집하고 제어한다.
글로벌 스마트시티(스마트 매장 에너지 관리) | - 실내 온도, 밀집도와 같은 환경 요소들도 파악하여 서비스 제공 - 빅데이터를 사용하여 적절한 에너지 사용 방법 알림

와 같은 개선점을 찾을 수 있었음.

이에 따른 구체적 해결방안으로

에너지 사용량을 파악하기 위해 에너지 사용량을 시각화 해야함.

- 사용량을 그래프를 사용하여 사용자가 알아보기 쉽게 제공.

- 지정한 사용량 초과 및 비정상적인 사용량 인식 시에 사용자에게 알림 제공

각 에너지 사용량을 측정하는 센서 데이터들을 모아 딥러닝을 통해 자동적인 관리 시스템을 구축한다.

- 각 요인에 따라 자동적으로 기기들을 제어하고, 수동적인 제어 역시 스마트폰이나, PC로 제어 가능하다.

- 제어된 로그들은 사용자에게 앱이나 웹의 형태로 제공된다.

## 1-2 프로젝트 개발 목표

1) 연구 및 개발 목표

IoT를 사용하여 다양한 에너지 사용량을 측정하고, 측정된 데이터를 빅데이터를 통해 분석하여 에너지를 효율적으로 사용하도록 사용자에게 알맞은 사용방법을 추천할 수 있도록 한다. 또한 인공지능에 의해 각종 에너지를 통제하고 사용자가 원격으로도 제어가 가능하도록 한다.

2) 기능정의
- 사용자에게 에너지 사용량을 시각화하여 보여준다.
- 에너지 소비 솔루션을 인공지능을 통해 제공한다.
- 에너지 소비 피크 시간에 대한 정보를 인공지능을 통해 분석하여 제공한다.
- 절감 효과에 대한 결과 데이터를 제공한다.
- 에너지는 전기, 온도로 정의한다.
- 사용량에 대한 기준을 정하고, 초과했을 때 알림 기능을 제공한다.
- 웹으로 모니터링 시스템을 제공한다.
- 모든 에너지는 스마트폰 어플리케이션을 통해 제어가 가능하다.
- 에너지 소비에 대한 제어는 인공지능과 사용자에 의해 제어된다.
- 날씨, 유동인구, 시간 데이터에 대한 정보를 사용하여 데이터를 분석한다.
- 에너지 데이터는 외부 서버 데이터베이스에 저장된다.
- 음성 인식을 통해 제어가 가능하도록 한다.

## 1-3 팀 역할 분담

| 김재현 | 이영채 | 김영민 | 김동혁
자료수집 | - HTML, JSP - Android Studio | - AWS RDS - 영상 처리 | - Google colab - 머신 러닝 모델 | - 라즈베리파이 - Atmega, 센서
설 계 | - 정보 웹 페이지 - 앱 | - 데이터 베이스 설계 - 모션 인식 개발 | - 머신 러닝 모델 적용 | - 라즈베리파이와 Atmega 연동
구 현 | - 웹페이지에 정보 표시 - 앱으로도 호환 | - 데이터 베이스 구축하여 데이터 관리 - 카메라를 이용한 모션 인식 | - 머신 러닝을 통해 결과 예측 | - 라즈베리파이에서 수집한 데이터 전송 - Atmega를 이용한 데이터 수집
테스트 | - 머신 러닝 - 예측 결과 - 웹 페이지, 앱 연동 - 라즈베리파이, Atmega 연동 및 데이터 수집

## 1-4 개발 일정

## 1-5 개발 환경

스마트 플러그 | NODEMCU | Esp8266 탑재. 인터넷 접속과 데이터 수집을 수행
| ACS-712 | 교류전류데이터 수집
| DHT-22 | 온습도 측정
| 5V relay | 5v 구동 릴레이, 전자기기 전원제어
| AC-DC컨버터 | 교류전원을 사용하여 보드, 센서를 구동

허브 | Arduino uno | 센서데이터 수집용(analog)
| SCT-013 | 비접촉 전류센서 (배전반 사용)
| Raspberry 3b+ | 영상처리, 아두이노 전원제공, 인터넷 접속
| Pi camera | 손님인식용 카메라
| 적외선 송,수신 센서 | 리모콘의 신호를 복제하여 기기제어

S/W | 서버 | Apache Tomcat 9.0 / Ubuntu 18.0.4 LTS
| DB | RDS for MySQL 8.0
| 머신 러닝 | Google Colaboratory
| 시각화 | Grafana
| 모션 인식 | OpenCV

# 2. 본론

주요 내용 | 2-1. 개발 내용 1) 환경 데이터 수집 2) 스마트 플러그 3) 제어 허브(배전반 측정용) 4) 머신 러닝 5) 웹 6) 데이터 베이스 2-2. 문제 및 해결 방안 2-3. 수행 시나리오 1) 구성도 2) 데이터 수집 시나리오 3) 데이터 저장 & 머신 러닝 시나리오 4) 사용자 인터페이스 시나리오 5) 제어 시나리오 2-4. 상세 설계 1) 유스케이스 다이어그램 2) 클래스 다이어그램 2-1) Display 2-2) MachineLearning 2-3) Sensor 1) PeopleRecogSensor 2) ampSensor 3) DHTSensor 2-4) Control 1) IRControl 1-1) AirControl 1-2) MonitorControl 2) PlugControl 3) GUI 화면 설계 3-1) 로그인 화면 3-2) 메인 화면(전체 모니터링) 3-3) 실시간 기상데이터 3-4) 사용비율 비교 3-5) 에너지 사용 예측 3-6) 기간별 사용량 3-7) 에너지 제어 3-8) 문의

## 2-1. 개발 내용

1) 환경 데이터 수집


2) 스마트 플러그

3) 제어 허브 (배전반 측정용)

4) 머신 러닝

5) 웹


6) 데이터 베이스

## 2-2 문제 및 해결 방안

문제 | 시스템을 사용하기 위한 인터페이스는 어떻게 구현할 것인가
해결 방안 | 스프링 프레임워크를 이용하여 웹을 구현하고 Apache Tomcat을 이용해 서버를 운영한다. 웹은 사용자에게 실제 에너지 사용량, 예상 에너지 사용량, 에너지 절감량, 기기 제어 등의 기능을 제공한다.

문제 | 전력데이터를 어떻게 수집할 것인가?
해결 방안 | 전력을 바로 구할수 있는 센서는 존재하지 않았고 전류센서로 전압을 곱해 전력을 구할 수밖에 없었다. 다만 여기서 일반적인 전류센서의 경우 접촉 방식으로 전선을 단선하여 측정하는 방식이었는데 저 전류의 경우 크게 위험하지않지만 에어컨이나 높은 전류가 흐르는 제품의 경우 단선하여 연결하는데에 큰 부담이 되었다. 이에따라 조사중 비접촉 전류센서인 SCT 013 제품을 찾아 배전반에 매설하는 방식으로 전력을 측정하도록 하였다.

문제 | 제품을 어떻게 제어할 것인가?
해결 방안 | 단순한 제품들이라면 그저 전원을 끊고 연결하기만하면 충분하지만 전선이 직접적으로 연결되어있지않은 즉, 비접촉 전류센서를 이용하는 제품의 경우 제어가 어려웠다. 에어컨이 가장 큰 경우였는데 고민중 IR(적외선) 신호를 이용해 기존 리모콘의 적외선 신호를 복제하여 원거리에서 풍량, 온도등을 제어하는 방법을 고안했다. 이 방법은 단순하게 에어컨 뿐만 아니라 전선이 매설되어있는 전자기기 (프로젝터등) 과 같은 기기의 제어에도 효과적일 것이라 생각한다.

문제 | 사람 인식을 함에 있어, 정면 외의 모습은 인식이 불가한 문제를 어떻게 해결할 것인가?
해결 방안 | 사람의 뒷 모습이나 옆 모습, 앉아있는 모습까지 학습시키는 것에 무리가 있다고 판단하여 움직임을 감지하는 방법으로 변경하기로 했다. 데이터베이스에 전송할 때는 5분 내에 움직임이 감지되면 1을 전송하여주고, 이외에는 0을 전송하도록 했다.

문제 | 머신러닝을 어떤 분야에 적용할 것인가?
해결 방안 | 초기에 대략적인 구상으로만 머신러닝을 해당 졸업 작품에 접목하여 적용 범위가 불명확했었다. 팀원들과 충분히 토의한 결과 수집한 데이터를 통해 미래의 전력 사용량을 예측하는 분야에서 머신러닝을 접목시킬 수 있다고 결론을 도출하였다. 현재 딥러닝 모델중 LSTM 모델과 Facebook에서 개발한 Prophet 모델을 사용 모델로 고려중으고, 현재 수집 중인 데이터에 대해 더 효율적인 모델을 찾기 위해 노력하겠다.

## 2-3 수행 시나리오

1) 구성도
2) 데이터 수집 시나리오
      1. 매장 내 전력사용량을 전류센서를 통해 수집한다.


      2. 매장 내 실내온습도를 DHT22 센서를 통해 수집한다.
      3. 매장 내 카메라를 이용하여 매장내 손님수를 분석하여 라즈베리파이에 유선으로 저장한다.
3) 시스템 수행 시나리오 – 데이터 저장 & 머신러닝
1. 라즈베리파이에서 센서데이터를 데이터베이스로wifi를 통해 전송한다.
2. 데이터베이스에서는 구글 클라우드로 데이터를 제공해준다.
3. 기상청으로부터 외부 날씨 데이터를 API를 통해 받아온다.
4. 수집한 데이터들을 통한 머신러닝을 통해 예측전력값을 구한다.
5. 예측데이터를 데이터 베이스에 저장한다.
4) 시스템 수행 시나리오 – 사용자 인터페이스
      1. 데이터베이스에 저장된 데이터를 시각화하여 웹서버로 전송한다.
      2. 웹서버는 사용자에게 인터페이스를 제공한다.
5) 시스템 수행 시나리오 – 제어


      1. 사용자 인터페이스에서 제어명령을 내린다.
      2. 해당 명령은 웹서버를 거쳐 원격제어 모듈로 전송된다.
      3. IR신호, 및 릴레이를 사용하여 전열기구, 전등, 플러그, 모니터 등을 제어한다.

## 2-4 상세 설계

1) 유스케이스 다이어그램
2) 클래스 다이어그램

2-1) Display

설명 | 웹에서 데이터 베이스의 정보를 이용하여 시간별 예측 전력 사용량, 현재 전력 사용량, 기기를 제어해 절감된 전력량을 시각화하여 사용자한테 제공한다.
메서드 | public showChart(self, object):void | 데이터를 시각화하여 사용자한테 제공한다.
| public getData(String,datetime) : object | 데이터 베이스에서 현재 사용중인 데이터를 가져온다.
| public getPredictData(String): float[][] | 데이터 베이스에서 머신러닝을 통해 구한 예측 전력값을 가져온다.

2-2) MachineLearning

설명 | Google Colaboratory를 통해 데이터 베이스에 저장된 현재 사용전력, 시간, 온습도, 인구 밀도를 활용하여 이후의 예측 소비 전력을 계산한다.
메서드 | public getData(String, datetime, datetime) : object | 데이터 베이스에서 머신러닝에 활용할 데이터를 가져온다.
| public AnalyzeData(object): float | 데이터를 머신러닝을 통해 분석하여 예측값을 도출한다.
| public sendData(String, datetime, float) : int | 머신러닝을 통해 도출한 값을 데이터베이스로 보낸다.

2-3) Sensor

설명 | 카메라, 온습도 센서, 조명 센서를 추상화한 클래스. 각각의 센서 클래스들이 상속하여 사용한다.
메서드 | public collectData(void) : void | 각 센서로부터 데이터를 gpio및 아날로그 핀을 통해 수집한다.
| public sendData(void) : void | 수집된 데이터를 사전에 정의해둔 sql서버로 전송한다.
| public setUpDatetime(void) : int | 아두이노 보드의 wifi연결을 통해 NTP서버로부터 시간을 받아와 동기화 한다.

1) PeopleRecogSensor

설명 | 카메라를 이용해 매장내의 손님수를 API를 사용하여 인식한다.
메서드 | public collectData(void) : void | 각 센서로부터 데이터를 gpio및 아날로그 핀을 통해 수집한다.

2) ampSensor

설명 | ACS712센서 및 SCT013센서를 이용해 전류를 측정한다.
메서드 | public sendData(int, datetime, float) : int | 전류센서의 데이터를 데이터베이스 로 현재 시간과 함꼐 전송한다.
| public collectData(int) : int | 전류데이터를 센서로부터 수집한다.

3) DHTSensor

설명 | DHT22 센서를 이용하여 매장내의 온/습도를 측정한다.
메서드 | public sendData(int, datetime, int, int) : int | 온습도 센서의 데이터를 데이터베이스로 전송한다.
| public collectData(int) : int[] | 온습도 데이터를 측정하고 이에 대한 결과를 배열로 반환한다.

2-4) Control

설명 | 자체 제작한 스마트 플러그, 배전반을 조작하는 인터페이스 인터페이스를 이용하여 각각의 컨트롤러에 연결된 기기를 제어한다.
메서드 | public deviceOn(int): int | 디바이스의 전원을 연결된 릴레이를 통해 켜는 함수이다.
| public deviceOff(int): int | 디바이스의 전원을 연결된 릴레이를 통해 끄는 함수이다.

1) IRControl

설명 | 적외선 리모컨을 사용하는 제품의 제어를 담당하는 클래스이다. AirControl과 MonitorControl에 상속을 해준다.
메서드 | public copySignal(void): ulong | 리모컨의 IR신호를 시스템에 저장받는 함수이다.

1-1) AirControl

설명 | IRControl에서 상속을 받아 바람 세기와 온도를 조절하는 클래스이다.
메서드 | public controlTemp(ulong) : int | 냉난방기의 온도를 조절하는 함수이다.
| public controlPower(ulong) : int | 냉난방기의 바람 세기를 조절을 하는 함수이다.

1-2) MonitorControl

설명 | IRControl에서 상속을 받아 TV를 제어하는 클래스이다.
메서드 | public deviceTVOn(ulong): void | TV의 전원을 켜는 함수이다.
| public deviceTVOff(ulong): void | TV의 전원을 끄는 함수이다.

2) PlugControl

설명 | 스마트 플러그의 제어를 하는 클래스이다. Control interface를 사용한다.
메서드 | public relayControl(void): int | 릴레이를 통해 스마트 플러그의 장비를 제어한다.

2-5) DB_interface

설명 | AWS RDS를 사용할 수 있는 데이터베이스 인터페이스. 서버 주소, 사용자 정보를 이용하여 데이터 베이스를 사용한다.
메서드 | public loginServer(IPAddress, char, char): int | 데이터 베이스에 매장별 접속을 할 수 있게 해주는 함수이다.
| public addNewStore() : int | 데이터베이스에 새로운관리대상 매장을 추가하는 메소드

3) GUI 화면 설계

웹 화면설계

  3-1) 로그인 화면
  3-2) 메인화면(전체 모니터링)


  3-3) 실시간 기상데이터
  3-4) 사용비율 비교
  3-5) 에너지 사용 예측


  3-6) 기간별 사용량
  3-7) 에너지 제어
  3-8) 문의


상세 설명

- 사용자는 매장에 부여된 아이디와 비밀번호를 통해 웹으로 접근을 한다.
- 로그인 후 전체적인 에너지의 모니터링을 하는 메인 페이지가 출력된다.
- 왼쪽의 네비게이션 바를 통해 원하는 메뉴로 접근한다.
- 각각의 메뉴를 통해 사용자에게 유용한 정보를 제공한다.
- 제어 메뉴에서는 사용자가 전자기기를 제어할 수 있도록 한다.

## 2-5. Prototype

2-5-1. Web 화면

1) 첫 시작 화면

첫 시작화면


- 매장명, 아이디, 비밀번호 입력
- 매장, 아이디, 비밀번호 미입력하면 경고창 출력
- 매장명, 아이디, 비밀번호가 틀리면 오류문 출력
- 사용자 계정 관리하는 관리자 계정 추가 예정

개발 예정 사항

- 관리자 계정 등록
- 관리자 계정이 회원 정보 수정, 생성, 삭제 기능 추가
- 디자인 변경

2) Home 화면

Home 화면

- 버튼으로 페이지 전환
- 로그아웃 클릭 시 시작화면으로 돌아감
- 각 페이지 버튼 클릭 시 그래프 출력

개발 예정 사항

- 환경, 에어컨, 조명에 대한 그래프 페이지 구현
- 디자인 변경

3) Smart_plug 그래프 화면

Smart_plug 화면

- 스마트 플러그로 측정한 전류값 그래프로 출력

2-5-2. H/W

스마트 플러그

작동모습


그림 1 : 대시보드에서 off상태


그림 2 : 대시보드 전원 on상태 전등켜짐

- 전류센서 , 릴레이, NODEMCU로 구성되어 있으며 릴레이를 통해 전원 연결 차단 제어가능함.
- 안전상의 문제를 미연에 방지하기 위해 누전차단회로가 탑재된 플러그를 사용함.
- Adafruit io 대시보드를 통해 휴대용 디바이스로도 전원연결을 제어할 수 있도록 함.

개발 예정 사항

- 기존의 회로를 좀더 정리하여 미관상으로도 보기 좋게 셋팅 하며, 따로 3d프린팅을 다시 진행하여 부품들을 피스로 고정할 수 있도록 조절할 예정.

IR제어 허브


그림 3 : IR제어허브


그림 4 : 허브 내부


그림 5 : 허브를 제어하기위한 대시보드

- 허브 기기는 스마트 플러그를 사용할 수 없는 전자기기를 적외선 신호를 사용하여 제어하고자 함.
- IR 신호 제어는 adafruit io 대시보드를 통해 제어될 수 있음.
- 허브의 라즈베리파이를 통해 현재 ip기반으로 현재 위치의 날씨를 데이터베이스로 전송함.
- 라즈베리파이에 달린 카메라를 통해 사람의 움직임을 인식하여 공간 내 사람 여부를 데이터베이스에 전송함.

개발 예정 사항

- 내부 부품의 변화로 인해 달라진 구조에 맞추기 위해 새롭게 3d프린팅을 진행할 예정
- IR전송센서의 전송거리가 짧기에 회로의 구성과 다른 센서를 구매하여 보다 넓은 범위를 제어할 수 있도록 변경예정
- IR 신호를 사용자가 직접 추가 할 수 있는 기능 구현예정 (현재는 개발과정에서 매핑해놓은 신호만 제어가능)
- 실내온도 측정기능 스마트 콘센트에서 허브로 기능이전

배전반 전류측정기

- 50A 제품을 사용하여 일반적인 매장용 배전반에 사용할 수 있도록 함.
- 비접촉 전류센서이기 때문에 누전의 가능성이 낮음
- 스마트 플러그로 측정 불가능한 전류를 측정하기 위한 제품임 (고 전류)

개발예정사항

- 회로가 노출되어 있는 상황이기 때문에 3d프린팅을 통해 케이스 제작 예정.

## 2-6. 테스트

테스트 대상 | 테스트 조건 | 예상 결과 | 실제 결과
기기 제어 | 카메라를 통해 실시간으로 확인 했을 때 손님의 유무에 따라 스마트 플러그 상태 조정 | 손님이 없으면 꺼진 상태, 손님이 있으면 준비 상태(전력 대기 상태) | 구현 완료
전등 제어 | 카메라를 통해 손님의 유무에 따라 전등 밝기 조절 | 손님이 없는 곳은 평소보다 밝기를 낮춘다. | 사람이 없는 구역을 지정하지 못하여 전체적으로 사람이 있을 때 밝기 조절
카메라 | 얼굴 인식을 통해 사람을 인식 | 인식한 사람의 얼굴 수를 데이터 베이스에 저장 | 얼굴 인식을 위한 카메라 및 제어 프로그램의 부재로 모션 인식을 하여 모션 수를 데이터 베이스에 저장
기기별 사용/절감 전력 그래프 | 스마트 플러그나 배전반을 통해 전력을 수집하는 기기들의 전력 사용량 시각화 | 측정하고 있는 각 기기들의 전력 사용량, 절감량을 그래프로 출력 | 구현 완료

## 2-7. 코딩

2-7-1. 웹 컨트롤러

1) 로그인 페이지


2) 메인 페이지
3) 스마트 플러그 페이지
4) 로그아웃

2-7-2. 로그인 JSP

1) 매장명, 아이디, 비밀번호로 로그인


2-7-3. 홈 화면 JSP

2-7-4. 그래프 화면 JSP

1) dataRow에 데이터를 넣어 그래프 구현


2-7-5. 스마트 플러그 동작 코드

1) 와이파이 접속 및 보드상에서 인터넷시간 받아오는 코드
2) 5분마다 DB에 접근하여 환경데이터 입력하는 코드
3) 교류전류의 RMS값을 측정하는 코드


4) adafruitIO에서 전류차단 / 전류연결 코드

2-7-6. IR 허브 동작 코드

1) NODEMCU IR관련 센서 핀맵 설정


2) 각각의 기기제어에 필요한 IR신호값 매핑
3) Adafruit IO 피드 접속하는 코드

2-7-7. 카메라 모션 인식 코드

1) 모션 인식하고, 온도와 습도를 기상청에서 가져와 데이터베이스에 전송 하는 함수


# 별첨 1

## 필요 기술 및 참고 문헌

### 1) 관련 연구 사례

- 2017년 차세대에너지연구소 고유과제 결과 보고서

https://scienceon.kisti.re.kr/commons/util/originalView.do?cn=TRKO201800035622&dbt=TRKO&rn=

- KT meg

http://www.enet.or.kr/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 pp. 2-18

- 빌딩 에너지 관리 시스템의 기술 및 표준화 동향

https://www.google.co.kr/url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 (https://www.google.co.kr/url?rct=j&q=&esrc=s&cd=)

- 오파워

https://www.hellot.net/new_hellot/magazine/magazine_read.html?code=205&sub=001&idx=44952&page=1&list=all

- 글로벌 스마트 시티

http://www.k-smartcity.kr/service1/service07.php

### 2) 사용 라이브러리

- 아두이노 DHT 라이브러리 https://github.com/adafruit/DHT-sensor-library
- ESP8266 인터넷시간 알아보는 라이브러리 https://github.com/mcxiaoke/ESPDateTime
- Mysql connector 척벨 (https://github.com/ChuckBell/MySQL_Connector_Arduino)
- SCT-013 사용관련 회로참고 https://learn.openenergymonitor.org/electricity-monitoring/ct-sensors/how-to-build-an-arduino-energy-monitor-measuring-current-only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
- Adafruit IO 대시보드 API (https://io.adafruit.com/api/docs/#adafruit-io-http-api )
- IRremote Arduino 라이브러리 https://github.com/Arduino-IRremote/Arduino-IRremote

### 3) 화면 설계

- 라임 ICT http://limeict.co.kr/product_cb.html

### 4) 머신 러닝

- 시계열 예측 https://www.tensorflow.org/tutorials/structured_data/time_series
- Prophet https://facebook.github.io/prophet/docs/quick_start.html#python-api
- LSTM https://brunch.co.kr/@chris-song/9

### 5) Google Cloud Platform

- 역 지오 코딩 https://cloud.google.com/solutions/reverse-geocoding-geolocation-telemetry-cloud-maps-api?hl=ko
- IP Geolocation API https://geo.ipify.org/

### 6) Web

- Google Charts.js

https://developers.google.com/chart/interactive/docs/gallery/linechart

- Spring4 https://github.com/minsoojun/Spring4
- Google Chart

https://github.com/89dev/JS-google_chart/blob/master/line_controls_chart.html

# 별첨 2

## 토스티아 카페 전력 사용 전자제품 목록

[냉난방기] 2개

제품명: 도시바 천장 에어컨 (18평 제품 기준)

호 칭 마 력 | | | 4HP
모 델 명 | | | MCY - MAP0401HT2K
냉방능력 | | (kW) | 12.4
| | (kcal/h) | 10,664
난방능력 | | (kW) | 12.5
| | (kcal/h) | 10,750
전기 특성 | 전 원 | (V-Ph-Hz) | 220-1-60
| 냉방 운전전류 | (A) | 14.58
| 냉방 소비전력 | (kW) | 2.98
| 난방 운전전류 | (A) | 13.60
| 난방 소비전력 | (kW) | 2.82
| 누전 차단기 | (A) | 32
압축기 | | (Type) | DC Inverter x 1ea
사용냉매 | | (Type) | R 410A
외형크기(HxWxD) | | (mm) | 1,340 x 900 x 320

Note: 1. 능력산출기준
냉방: 실내온도 27℃ DB / 19.5℃ WB, 실외온도 35℃ DB
난방: 실내온도 20℃ DB, 실외온도 7℃ DB / 6℃ WB
2. 본 제품은 인버터형이므로 부하에 따라 소비전력이 변합니다.

[led 메뉴판] 6개

제품명: led 발광판

http://www.mylumi.co.kr/news/1060 여기 연락해서 물어보기

대략 소비전력 18w

[천장등 (대)] 5개

소비전력 12w(미정)

[천장등 (소)] 7개


소비전력 7W(미정)

[음료 냉장고] 2개

소비전력 300W ~ 400W -> 업소일 경우 열고 닫는 경우가 평균보다 많이 더 클 것으로 추정한다고 함

[업소용 냉장고] 2개

제품명: 우성 GWS-150RT

소비전력 전화해서 물어봐야 함

[얼음 제빙기]

제품명: JETICE-210W

정격 소비전력 -> 1250W

[커피 머신]

제품명: FIORENZATO VENEZIA 2GR


소비전력 -> 3500W

[커피 그라인더]

ANFIM Super Caimano on Demand 2

소비전력 -> 400W

[핫 워터 디스펜서]

소비전력 -> 2000~ 2100W

[미니 오븐] 3개

소비전력 -> 800W

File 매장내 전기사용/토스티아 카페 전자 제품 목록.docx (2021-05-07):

토스티아 카페 전력 사용 전자제품 목록

[냉난방기] 2개

-> 도시바 천장 에어컨 (18평 제품 기준)


호 칭 마 력 | | | 4HP
모 델 명 | | | MCY - MAP0401HT2K
냉방능력 | | (kW) | 12.4
| | (kcal/h) | 10,664
난방능력 | | (kW) | 12.5
| | (kcal/h) | 10,750
전기 특성 | 전 원 | (V-Ph-Hz) | 220-1-60
| 냉방 운전전류 | (A) | 14.58
| 냉방 소비전력 | (kW) | 2.98
| 난방 운전전류 | (A) | 13.60
| 난방 소비전력 | (kW) | 2.82
| 누전 차단기 | (A) | 32
압축기 | | (Type) | DC Inverter x 1ea
사용냉매 | | (Type) | R 410A
외형크기(HxWxD) | | (mm) | 1,340 x 900 x 320

Note: 1. 능력산출기준
냉방: 실내온도 27℃ DB / 19.5℃ WB, 실외온도 35℃ DB
난방: 실내온도 20℃ DB, 실외온도 7℃ DB / 6℃ WB
2. 본 제품은 인버터형이므로 부하에 따라 소비전력이 변합니다.

[led 메뉴판] 6개


http://www.mylumi.co.kr/news/1060 여기 연락해서 물어보기

대략 소비전력 18w


[천장등 (대)] 5개


소비전력 12w(미정)

[천장등 (소)] 7개


소비전력 7W(미정)

[음료 냉장고] 2개


소비전력 300W ~ 400W -> 업소일 경우 열고 닫는 경우가 평균보다 많이 더 클 것으로 추정한다고 함

[업소용 냉장고] 2개

우성 GWS-150RT ->


소비전력 전화해서 물어봐야 함

[얼음 제빙기] 1개

JETICE-210W


정격 소비전력 -> 1250W

[커피 머신]

FIORENZATO VENEZIA 2GR


소비전력 -> 3500W

[커피 그라인더] 1개

ANFIM Super Caimano on Demand 2


소비전력 -> 400W

[핫 워터 디스펜서] 1개


소비전력 -> 2000~ 2100W

[미니 오븐] 3개


소비전력 -> 800W

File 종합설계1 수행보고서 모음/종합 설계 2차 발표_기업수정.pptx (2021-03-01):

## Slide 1

- IoT기반 에너지 매니저 시스템

- IoT Based Energy Management System
- Net-KTI

학번 : 2016156007 이름 : 김영민 지도교수 : 김영곤 교수님
학번 : 2016156003 이름 : 김동혁 지도교수 : 김영곤 교수님
학번 : 2016156009 이름 : 김재현 지도교수 : 김영곤 교수님
학번 : 2016156022 이름 : 이영채 지도교수 : 김영곤 교수님

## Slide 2

목차

1. 종합설계 개요
2. 관련 연구 및 사례
3. 시스템 수행 시나리오
4. 시스템 구성도
5. 시스템 모듈 상세설계
6. 개발환경 및 개발방법
7. 데모환경 설계
8. 업무 분담
9. 종합설계 수행일정
10. 필요기술 및 참고문헌

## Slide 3

1. 종합설계 개요

지난 발표에서의 지적 사항
주제에 대해 적용하는 장소가 구체적이지 않다.
전력 수집 대상이 명확하지 않다.
구상도에서 음성 인식과 카메라의 필요성이 설명되지 않았다.
머신 러닝의 이유에 대해 명확하지 않다.
지적 사항에 대한 답변
주제에 대해 적용하는 장소는 매장으로 선정했다.
냉난방기, 조명, (스크린)
음성인식은 주제에 맞지 않아 제외하기로 하였고 카메라는 모션 인식을 통해 사람이 있는지 확인한다.
수집한 환경, 전력 데이터를 학습하여 전력 소비량을 예측하여 사용자에게 알려준다.

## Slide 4

1-1기업 지적사항

지난 발표에서의 지적 사항
하드웨어 / 허브 의 역할 각 부품의 역할 등이 명확히 정리된 장표가 없다.
클래스 설계와 통일되게 용어 정의가 명확히 필요
통신 방식에 대해서도 wifi or 블루투스 표기
지적 사항에 대한 답변
12 페이지에 말씀하신 허브와 스마트 플러그의 역할 추가했습니다
허브와 스마트플러그의 부품 등 상세한 내용은 28,29 페이지에 있습니다.

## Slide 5

1. 종합설계 개요

연구 개발 배경
매장에 손님이 없는 경우에도 지속적으로 전력이 소모되는 상황이 자주 발생
에너지 관리를 해줄 수 있는 시스템의 필요를 느낌
연구 개발 목표
IoT를 활용한 매장내 에너지 관리 시스템 구현
빅데이터, AI를 통한 최적화 시스템 구현
연구 개발 효과
매장 내 불필요한 에너지 사용을 줄일 수 있고 이로 인한 매장관리비용의 감소를 실현 가능함

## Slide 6

2. 관련 연구 및 사례 (출처 추가예정)

관련 연구 및 사례 | 설명 | 개선점
스마트빌딩 통합관리·E절감 솔루션 | 기기간 무선 통신 비용 절감 및 제어 용이 자체적인 지능형 에너지 절감 분석 시스템을 통해 에너지 절감 효과 개선 전문가만 제어가 가능함 | 관련 전문 지식을 보유하지 않은 일반 사용자도 이용하기 편하도록 인터페이스를 구현
오 파워 | 홈페이지를 통해 전기 사용량·전기요금 등의 정보를 제공 고객이 직접 확인하여 구체적인 절전 목표 수립이 가능 전기 사용량·전기요금 등을 그래프와 표로 표현 | IoT를 사용하여 에너지 장치 각각의 데이터를 수집하고 제어한다.
글로벌 스마트시티(스마트 매장 에너지 관리) | 기기 별 전력 사용량 실시간 모니터링 규칙 설정을 통한 실시간 알림 설정 규칙 설정을 통한 설비 자동 제어 매장 실내환경 실시간 모니터링 | 실내 온도, 밀집도와 같은 환경 요소들도 파악하여 서비스 제공 빅데이터를 사용하여 적절한 에너지 사용 방법 알림

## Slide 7

3. 시스템 수행 시나리오 – 데이터 수집


1. 매장 내 전력사용량을 전류센서를 통해 수집한다.
2. 매장 내 실내 온습도를 DHT22 센서를 이용하여 수집한다.
3. 매장내 카메라를 통해 매장 내 손님 수를 분석하여 라즈베리파이에 유선으로 저장한다.

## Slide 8

3. 시스템 수행 시나리오 – 데이터 저장 & 머신러닝


1. 라즈베리파이에서 센서데이터를 데이터베이스로 wifi를 통해 전송한다.
2. 데이터베이스에서는 구글 클라우드로 데이터를 제공해준다
3. 기상청으로부터 외부 날씨 데이터를 API를 통해 받아온다.
4. 수집한 데이터들을 통한 머신러닝을 통해 예측전력값을 구한다.
5. 예측데이터를 데이터 베이스에 저장한다.

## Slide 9

3. 시스템 수행 시나리오 – 사용자 인터페이스


1. 데이터베이스에 저장된 데이터를 시각화하여 웹서버로 전송한다.
2. 웹서버는 사용자에게 인터페이스를 제공한다.

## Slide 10

3. 시스템 수행 시나리오 - 제어


1. 사용자 인터페이스에서 제어명령을 내린다.
2. 해당 명령은 웹서버를 거쳐 원격제어 모듈로 전송된다.
3. IR신호, 및 릴레이를 사용하여 전열기구, 전등, 플러그, 모니터등 을 제어한다.

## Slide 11

4. 시스템 구성도


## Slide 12

5. 시스템 모듈 상세설계 – 하드웨어 종류

스마트 플러그 | IoT 제어 허브
→ 플러그를 사용하는 저전류 기기의 전류를 측정하기 위한 장치. 접촉 전류센서(ACS-712)를 이용해 전류를 측정함. 5V 릴레이를 통해 원격으로 전원을 차단하여 전자기기 제어 가능 플러그가 설치되어 있는 장소의 온/습도 측정 가능 측정한 데이터를 데이터 베이스로 전송함 | 플러그를 사용하지 못하는 고전류 기기의 전류를 측정하기 위한 장치. 비접촉 전류센서를 이용하여 50A까지의 전류측정가능 모션인식을 사용하여 공간 내 사람의 존재유무를 측정가능 측정한 데이터를 데이터 베이스로 전송함 릴레이를 사용하지못하는 전자기기의 리모컨 신호를 복제하여 제어하는 역할을 수행함

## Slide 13

5. 시스템 모듈 상세설계 – 스마트 플러그 회로도


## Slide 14

5. 시스템 모듈 상세설계 – 허브 회로도


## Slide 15

5. 시스템 모듈 상세설계 – 하드웨어

MySQL_Connection.h
분류 | 헤더파일 / DB접속 관련
기능 | 기기에서 DB접속

getVPP()
분류 | 전류센서/ 함수
기능 | 1초간 교류전류값의 최댓값을 받아옴
리턴값 | 실수형 전류값(아날로그)

DHT.h
분류 | 헤더파일 / 온습도 측정
기능 | DHT사용하여 온습도 측정

Wifi_connect()
분류 | 와이파이모듈 / 함수
기능 | 블루투스 모듈 동작 헤더파일
리턴 값 | void

setupDateTime()
분류 | 함수
기능 | 인터넷 ntp서버에서 시간을 받아 동기화
리턴값 | void

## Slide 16

5. 시스템 모듈 상세설계 – 하드웨어 흐름도

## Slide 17

5. 시스템 모듈 상세설계 – 제품 디자인


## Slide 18

5. 시스템 모듈 상세설계 – Class Diagram


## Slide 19

5. 시스템 모듈 상세설계 - Class

1) Display

설명 | 웹에서 데이터 베이스의 정보를 이용하여 시간별 예측 전력 사용량, 현재 전력 사용량, 기기를 제어해 절감된 전력량을 시각화하여 사용자한테 제공한다.
메서드 | public showChart(self, object):void | 데이터를 시각화하여 사용자한테 제공한다.
| public getData(String,datetime) : object | 데이터 베이스에서 현재 사용중인 데이터를 가져온다.
| public getPredictData(String): float[][] | 데이터 베이스에서 머신러닝을 통해 구한 예측 전력값을 가져온다.

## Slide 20

5. 시스템 모듈 상세설계 - Class

2)Machine Learning

설명 | Google Colaboratory를 통해 데이터 베이스에 저장된 현재 사용전력, 시간, 온 습도, 인구 밀도를 활용하여 이후의 예측 소비 전력을 계산한다.
메서드 | public getData(String, datetime, datetime) : object | 데이터 베이스에서 머신 러닝에 활용할 데이터를 가져온다.
| public AnalyzeData(object): float | 데이터를 머신 러닝을 통해 분석하여 예측 값을 도출한다.
| public sendData(String, datetime, float) : int | 머신 러닝을 통해 도출한 값을 데이터베이스로 보낸다.

3) Sensor

설명 | 허브의 모션인식 카메라, 스마트 플러그의 온 습도 센서, 전류 센서를 추상화한 클래스. 각각의 센서 클래스들이 상속하여 사용한다.
메서드 | public collectData(void) : void | 각 센서로부터 데이터를 gpio및 아날로그 핀을 통해 수집한다.
| public sendData(void) : void | 수집된 데이터를 사전에 정의해둔 sql서버로 wifi를 통해 전송한다.
| public setUpDatetime(void) : int | 아두이노 보드의 wifi 연결을 통해 NTP서버로부터 시간을 받아와 동기화 한다.

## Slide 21

5. 시스템 모듈 상세설계 - Class

3-1) PeopleRecogSensor

설명 | 허브의 모션인식 카메라를 이용해 매장내의 손님수를 API를 사용하여 인식한다.
메서드 | public collectData(void) : void | 각 센서로부터 데이터를 gpio및 아날로그 핀을 통해 수집한다.

3-2) ampSensor

설명 | 허브와 스마트플러그의 전류측정(ACS712및 SCT013) 센서를 이용해 전류를 측정한다.
메서드 | public sendData(int, datetime, float) : int | 전류센서의 데이터를 데이터베이스 로 현재 시간과 함께 wifi로 전송한다.
| public collectData(int) : int | 전류데이터를 센서로부터 수집한다.

3-3) DHTSensor

설명 | 스마트플러그의 온 습도(DHT22) 센서를 이용하여 매장내의 온/습도를 측정한다.
메서드 | public sendData(int, datetime, int, int) : int | 온 습도 센서의 데이터를 데이터베이스로 wifi를 통해 전송한다.
| public collectData(int) : int[] | 온 습도 데이터를 측정하고 이에 대한 결과를 배열로 반환한다.

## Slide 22

5. 시스템 모듈 상세설계 - Class

4) Control

설명 | 자체 제작한 스마트 플러그, 배전반에 연결된 전자기기를 제어하는 인터페이스 인터페이스를 이용하여 각각의 컨트롤러에 연결된 기기를 제어한다.
메서드 | public deviceOn(int): int | 스마트 플러그에 연결된 전자기기의 전원을 릴레이를 통해 켜는 함수이다.
| public deviceOff(int): int | 스마트 플러그에 연결된 전자기기의 전원을 연결된 릴레이를 통해 끄는 함수이다.

설명 | 적외선 리모컨을 사용하는 제품의 제어를 담당하는 클래스이다. AirControl과 MonitorControl에 상속을 해준다.
메서드 | public copySignal(void): ulong | 리모컨의 IR신호를 시스템에 저장 받는 함수이다.

4-1) IRControl

4-1-1) AirControl

설명 | IR Control에서 상속을 받아 냉난방기의 바람 세기와 온도를 조절하는 클래스이다.
메서드 | public controlTemp(ulong) : int | 냉난방기의 온도를 조절하는 함수이다.
| public controlPower(ulong) : int | 냉난방기의 바람 세기를 조절을 하는 함수이다.

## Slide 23

5. 시스템 모듈 상세설계 - Class

4-1-2) MonitorControl

설명 | IRControl에서 상속을 받아 TV를 제어하는 클래스이다.
메서드 | public deviceTVOn(ulong): void | TV의 전원을 켜는 함수이다.
| public deviceTVOff(ulong): void | TV의 전원을 끄는 함수이다.

4-2)PlugControl

설명 | 스마트 플러그의 릴레이를 통한 제어를 하는 클래스이다. Control interface를 사용한다.
메서드 | public relayControl(void): int | 릴레이를 통해 스마트 플러그에 연결된 장비를 제어한다.

5) DB_interface

설명 | AWS RDS를 사용할 수 있는 데이터베이스 인터페이스. 서버 주소, 사용자 정보를 이용하여 데이터 베이스를 사용한다.
메서드 | public loginServer(IPAddress, char, char): int | 데이터 베이스에 매장 별 접속을 할 수 있게 해주는 함수이다.
| public addNewStore() : int | 데이터베이스에 새로운 관리대상 매장을 추가하는 메소드

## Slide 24

5. 시스템 모듈 상세설계 - DB


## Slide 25

5. 시스템 모듈 상세설계 – 소프트웨어 흐름도

1) Machine Learning

2) Display


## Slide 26

5. 시스템 모듈 상세설계 – 제어 흐름도


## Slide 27

6. 개발 내용

1) 환경 데이터 수집

1. 매장 내 소비 전력, 온/습도 수집
- 자체 제작 스마트 플러그와 배전반 수집기를 통해 데이터를 수집한다.
2. 기상청에서 날씨 데이터 수집
- 기상청 API를 사용하여 해당날짜 기상데이터를 수집한다.
3. 매장 내 손님 유무 데이터 카메라로 수집
- 카메라를 설치하여 구역 내 손님의 유무를 확인한다.

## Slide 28

6. 개발 내용

2) 스마트 플러그

1. 스마트 플러그 개념
- 멀티탭 선을 단선하여 ESP8266 보드를 기반으로 전력센서와 릴레이를 통해 연결된 전자기기의 소비전력을 측정 / 제어 한다.
2. 사용 부품
- ESP 8266
- ACS 712
- DHT 22 (실내 온/습도 측정)
- 5V 릴레이
- Ac - Dc 컨버터
3. 특이사항
- 와이파이와 연결된 형태로 일정 시간마다 측정전류를 DB로 전송하고, 웹으로부터 릴레이 작동신호를 받으면 릴레이를 작동시킴으로써 연결된 전자기기를 제어한다.
- 개발환경은 아두이노IDE에 ESP8266보드를 추가하여 C로 개발한다.

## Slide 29

6. 개발 내용

3) 제어 허브 (배전반 측정용)

1. 허브 개념
- 현실적으로 단선하여 측정이 어려운 배전반의 경우 비접촉 전류센서를 사용하기위한 측정 도구.
- 더불어 전력측정뿐만이 아니라 카메라를 통한 손님인식 및 IR신호를 통한 기기제어를 실행한다.
2. 사용 부품
- Rasp Pi 3 b+
- Arduino uno
- IR 송 / 수신기
- 비접촉 전류센서 (SCT - 013)
- pi 카메라 5MP
3. 특이사항
- 아두이노는 라즈베리파이로 부터 5V 전원을 공급받아 전원을 일원화 한다.
- 연결된 IR 송수신기를 통해 전자기기 리모콘의 적외선 신호를 복제하여 전자기기를 제어한다.

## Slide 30

6. 개발 내용

4) 머신 러닝

1. 수집한 데이터를 통해 머신 러닝
- Google Colab 를 활용하여 수행한다.
- 전력 사용량과 온/습도, 날씨, 인원 수 등의 데이터들을 연계하여 머신 러닝을 진행한다.
- 전력과 나머지 데이터의 연관에 따른 예측 소비량을 보여준다.
2. 분석한 데이터를 AWS 데이터베이스에 전송한다.
- 시각화를 위해 분석한 데이터를 데이터베이스에 지속적으로 저장한다.

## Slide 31

6. 개발 내용

5) 웹

1. Spring Framework를 이용한 웹 개발
- Eclipse를 통해 Spring Framework를 사용하여 웹 구현한다.
- Apache Tomcat 9.0 서버를 이용한다.
2. 데이터 베이스에 저장된 수집한 데이터와 예측된 데이터를 시각화
- 스마트 플러그와 Hub를 통해 수집된 데이터를 시각화 하여 사용자한테 제공한다.
- 머신 러닝을 통해 예측한 데이터를 시각화 하여 사용자한테 제공한다.
3. 전력 기기 제어
- 사용자가 보낸 제어 신호를 스마트 플러그와 Hub에 전송한다.
- 스마트 플러그와 Hub에 연결된 전력 기기를 신호로 제어한다.
4. 절감량 계산
- 사용자한테 기기를 제어해 절감된 전력량을 시각화하여 표시한다.
5. 알림 수신
- 사용자에게 전력 절감이 필요한 기기를 알려준다.

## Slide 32

6. 개발 내용

6) 데이터 베이스

1. AWS RDS for MYSQL
- AWS RDS 클라우드 서비스를 사용하여 데이터베이스를 이용한다.
- MYSQL을 사용한다.
2. Entitiy는 아래와 같다.
- Store(매장)
- Account(계정)
- Env(환경)
- Smart_plug(스마트 플러그)
- Product(제품)
- Airconditioner(냉난방기)
- Light(조명)
- Hub(배전반 측정기)

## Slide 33

6. 개발 환경

스마트 플러그 | NODEMCU | Esp8266 탑재. 인터넷 접속과 데이터 수집을 수행
| ACS-712 | 교류전류데이터 수집
| DHT-22 | 온습도 측정
| 5V relay | 5v 구동 릴레이, 전자기기 전원제어
| AC-DC컨버터 | 교류전원을 사용하여 보드, 센서를 구동

허브 | Arduino uno | 센서데이터 수집용(analog)
| SCT-013 | 비접촉 전류센서 (배전반 사용)
| Raspberry 3b+ | 영상처리, 아두이노 전원제공, 인터넷 접속
| Pi camera | 손님인식용 카메라
| 적외선 송,수신 센서 | 리모콘의 신호를 복제하여 기기제어

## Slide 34

6. 개발 환경

S/W | 서버 | Apache Tomcat 9.0 / Ubuntu 18.0.4 LTS
| DB | RDS for MySQL 8.0
| 머신 러닝 | Google Colaboratory
| 시각화 | Grafana
| 모션 인식 | OpenCV

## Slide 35

7. 데모 환경

데모 환경 구성
- 스마트 플러그: 3D 프린팅으로 시제품 완성
- 허브: 3D 프린팅으로 시제품 완성
- 웹 서버: 센서 데이터를 데이터베이스에서 가져와 시각화
- 모니터: 웹 접속 및 확인

데모 순서
- 스마트 플러그 WiFi 연결
- 허브 WiFi 연결
- 각 센서로 데이터 측정
- 축적된 데이터로 예측 전력 도출
- 웹서버에서 데이터 시각화
- 모니터로 확인

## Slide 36

8. 수행 일정


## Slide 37

9. 업무 분담

| 김재현 | 이영채 | 김영민 | 김동혁
자료수집 | HTML, JSP Android Studio | AWS RDS for MySQL 영상 처리 | Google colab 머신 러닝 모델 | 라즈베리파이 Atmega, 센서
설 계 | 정보 웹 페이지 앱 | 데이터 베이스 설계 모션 인식 개발 | 머신 러닝 모델 적용 | 라즈베리파이와 Atmega 연동
구 현 | 웹페이지에 정보 표시 앱으로도 호환 | 데이터 베이스 구축하여 데이터 관리 카메라를 이용한 모션 인식 | 머신 러닝을 통해 결과 예측 | 라즈베리파이에서 수집한 데이터 전송 Atmega를 이용한 데이터 수집
테스트 | 머신 러닝 - 예측 결과 웹 페이지, 앱 연동 라즈베리파이, Atmega 연동 및 데이터 수집

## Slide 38

10. 필요기술 및 참고 문헌

- [관련 연구 사례]
- 2017년 차세대에너지연구소 고유과제 결과 보고서
https://scienceon.kisti.re.kr/commons/util/originalView.do?cn=TRKO201800035622&dbt=TRKO&rn=
- KT meg
http://www.enet.or.kr/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 pp. 2-18
- 빌딩 에너지 관리 시스템의 기술 및 표준화 동향
https://www.google.co.kr/url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 (https://www.google.co.kr/url?rct=j&q=&esrc=s&cd=)
- 오파워
https://www.hellot.net/new_hellot/magazine/magazine_read.html?code=205&sub=001&idx=44952&page=1&list=all
- 글로벌 스마트 시티
http://www.k-smartcity.kr/service1/service07.php

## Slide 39

10. 필요기술 및 참고 문헌

- [사용 라이브러리]
- 아두이노 DHT 라이브러리 https://github.com/adafruit/DHT-sensor-library
- ESP8266 인터넷시간 알아보는 라이브러리 https://github.com/mcxiaoke/ESPDateTime
- Mysql connector 척벨 (https://github.com/ChuckBell/MySQL_Connector_Arduino)
- SCT-013 사용관련 회로참고 https://learn.openenergymonitor.org/electricity-monitoring/ct-sensors/how-to-build-an-arduino-energy-monitor-measuring-current-only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
- [화면 설계]
- 라임 ICT http://limeict.co.kr/product_cb.html
- [머신러닝]
- 시계열 예측 https://www.tensorflow.org/tutorials/structured_data/time_series
- Prophet https://facebook.github.io/prophet/docs/quick_start.html#python-api
- LSTM https://brunch.co.kr/@chris-song/9
[Google Cloud Platform]
- 역 지오 코딩 https://cloud.google.com/solutions/reverse-geocoding-geolocation-telemetry-cloud-maps-api?hl=ko
- IP Geolocation API https://geo.ipify.org/

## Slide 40

10. GitHub

https://github.com/mugju/kpu_energy


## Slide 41

- THANK YOU

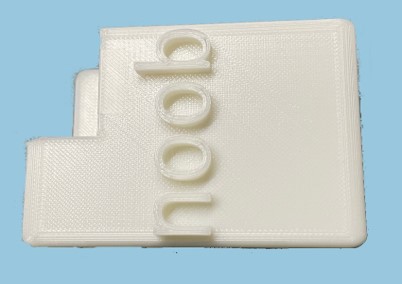
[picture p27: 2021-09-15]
Hardware/home.jpg

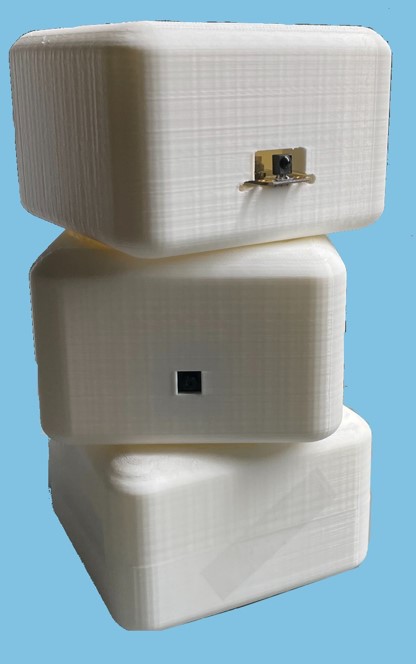
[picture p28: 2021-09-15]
Hardware/Hub.jpg

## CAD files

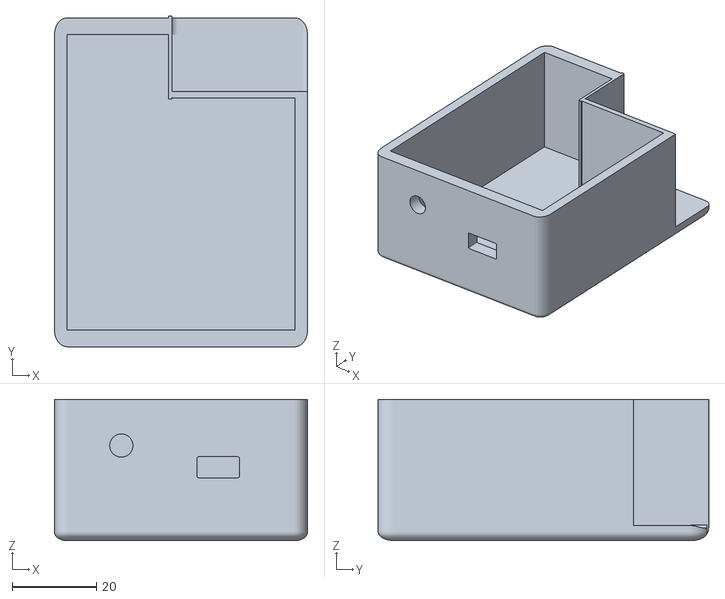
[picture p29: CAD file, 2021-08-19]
Hardware 3D file/3d 모델링 최신/졸작 모델링/배전반 바닥.stl
60.0 x 78.4 x 33.5

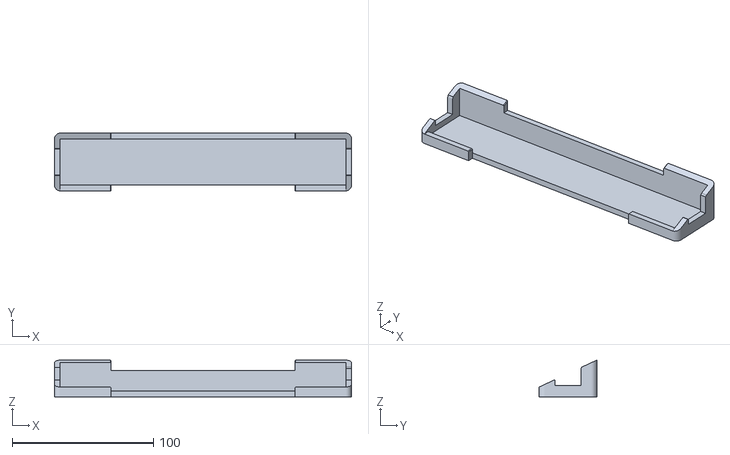
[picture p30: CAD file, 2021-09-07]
Hardware 3D file/Led/Led_Body.STL
210.0 x 40.8 x 26.0

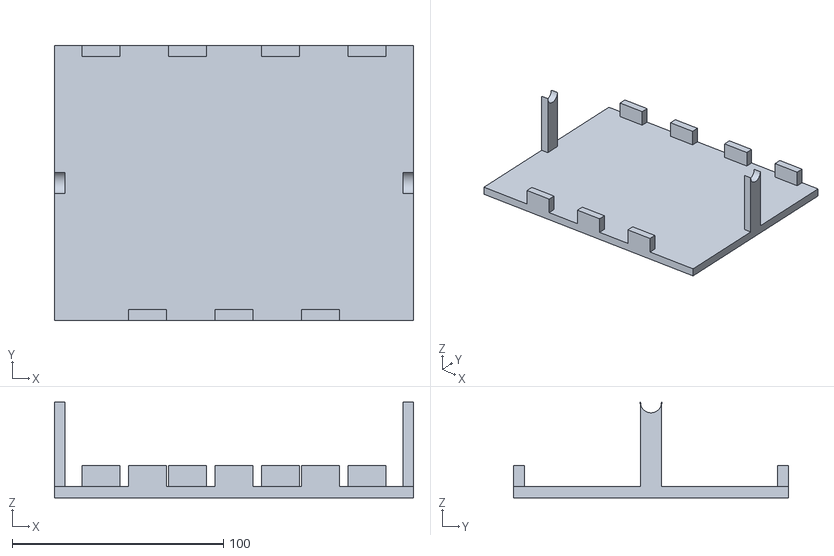
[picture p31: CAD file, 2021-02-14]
Hardware 3D file/스마트플러그 뚜껑.stl
170.0 x 130.0 x 45.2

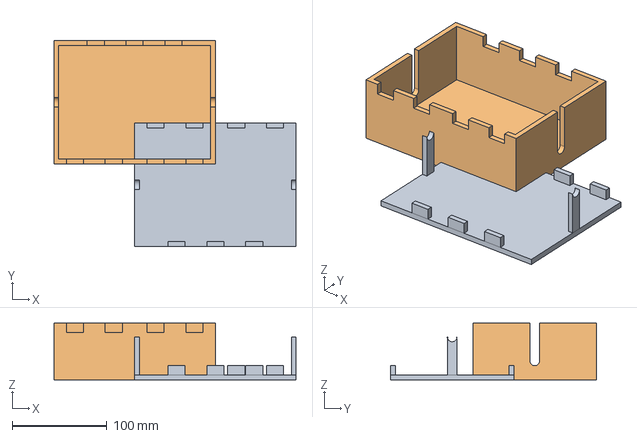
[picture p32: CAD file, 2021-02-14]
Hardware 3D file/스마트플러그/스마트플러그 바닥.stp
255.0 x 217.0 x 60.0 mm

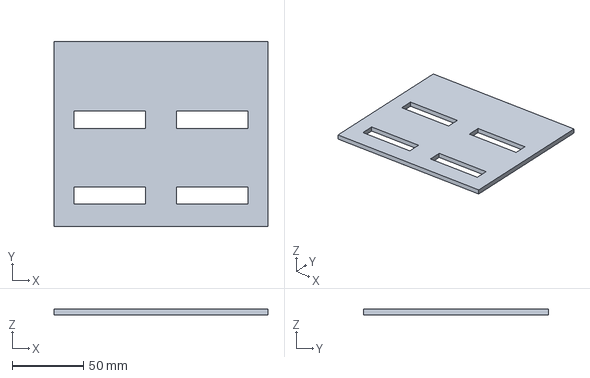
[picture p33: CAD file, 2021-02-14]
Hardware 3D file/허브/허브 뚜껑.stp
150.0 x 130.0 x 4.00 mm

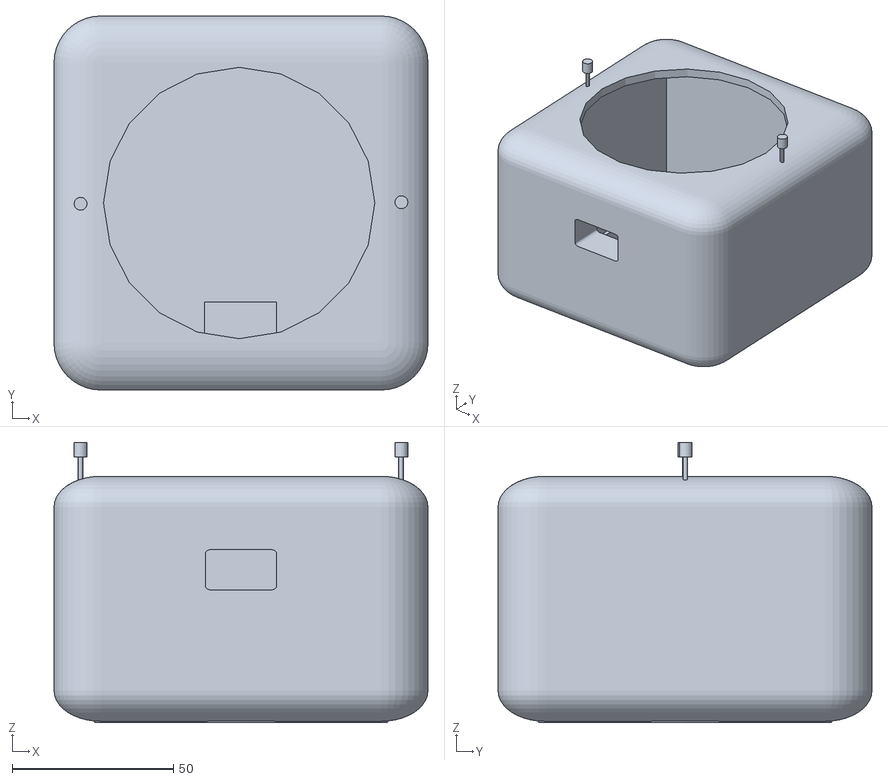
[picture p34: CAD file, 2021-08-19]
Hardware 3D file/3d 모델링 최신/졸작 모델링/3층 센서.stl
116.0 x 116.0 x 86.9

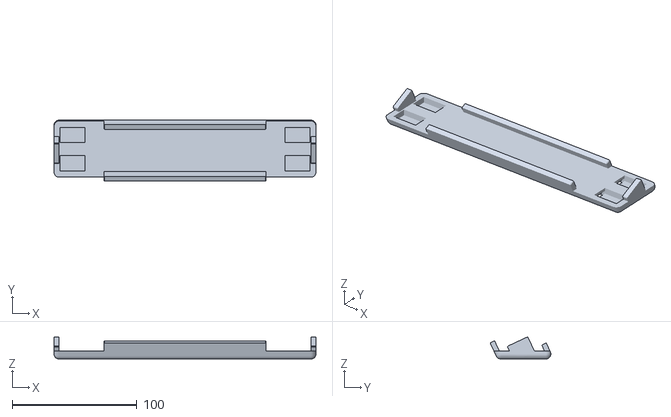
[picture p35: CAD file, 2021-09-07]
Hardware 3D file/Led/Led_Cover.STL
210.0 x 48.7 x 17.6

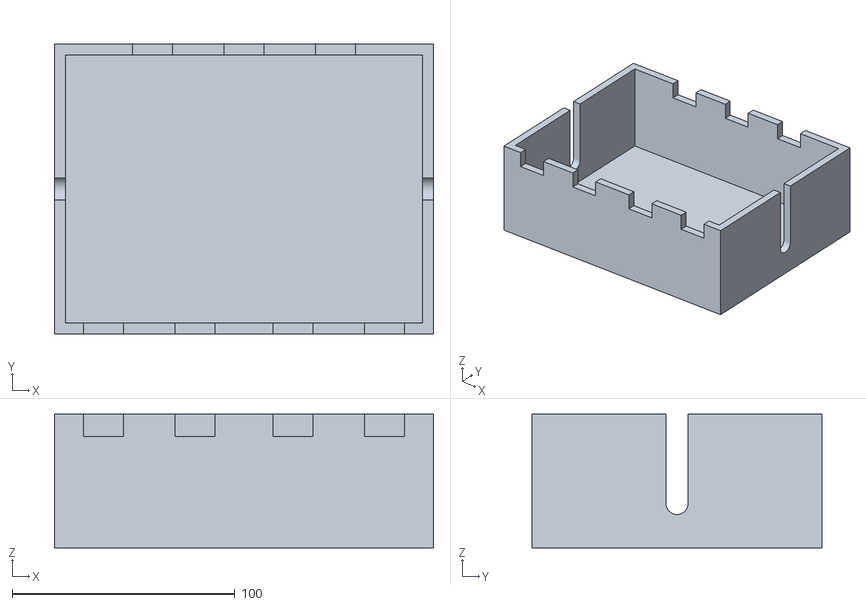
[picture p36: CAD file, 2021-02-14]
Hardware 3D file/스마트플러그 바닥.stl
170.0 x 130.0 x 60.0

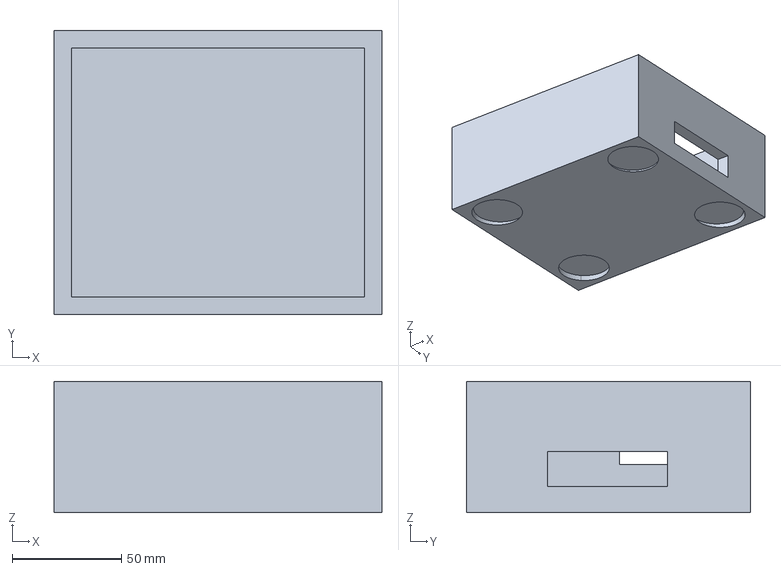
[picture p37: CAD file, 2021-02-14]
Hardware 3D file/허브/허브 몸통.stp
150.0 x 130.0 x 60.0 mm

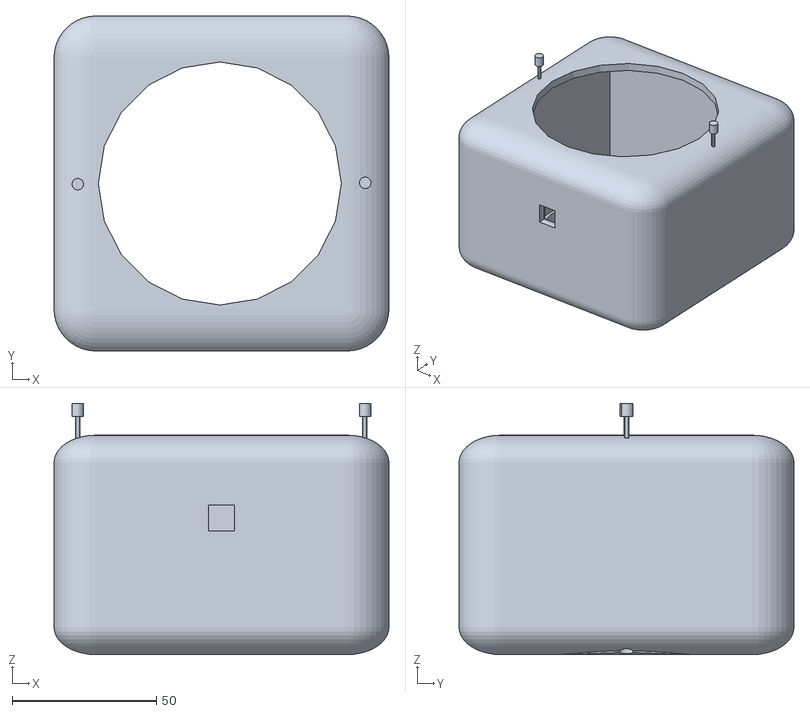
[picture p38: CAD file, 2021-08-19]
Hardware 3D file/3d 모델링 최신/졸작 모델링/2층 카메라.stl
116.0 x 116.0 x 87.0

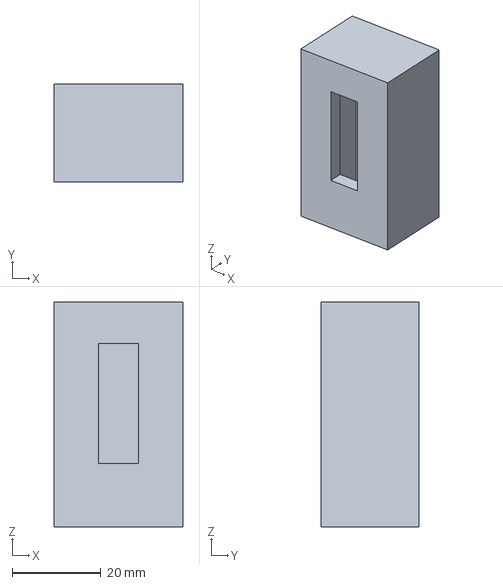
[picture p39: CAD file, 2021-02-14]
Hardware 3D file/허브/카메라뚜껑.stp
29.0 x 22.0 x 50.8 mm

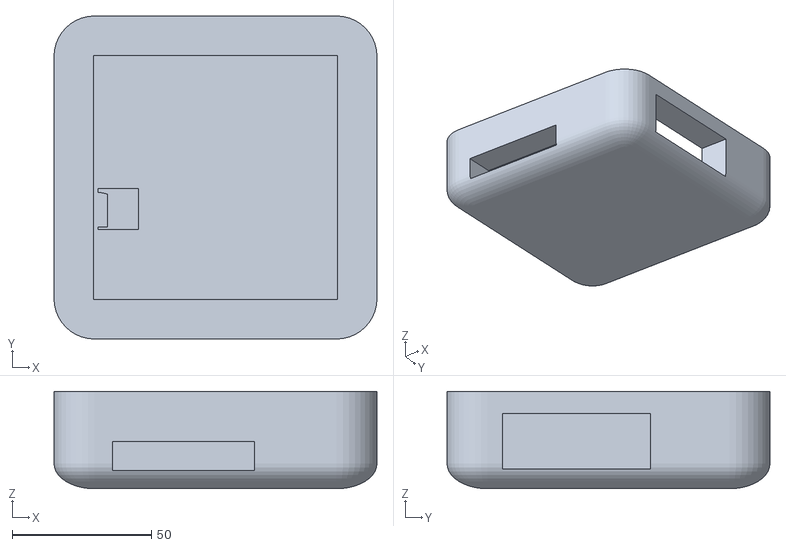
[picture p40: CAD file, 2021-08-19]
Hardware 3D file/3d 모델링 최신/졸작 모델링/1층 바닥.stl
116.0 x 116.0 x 35.0

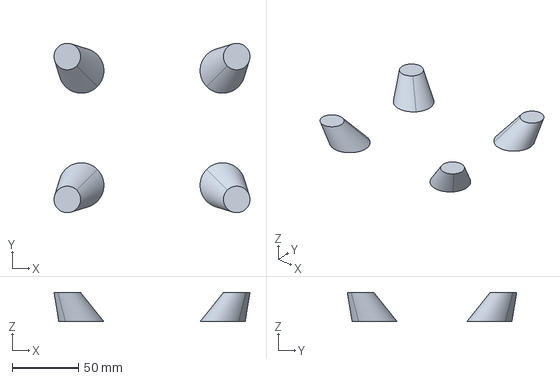
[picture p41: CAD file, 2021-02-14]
Hardware 3D file/허브/허브다리.stp
147.6 x 127.6 x 22.0 mm

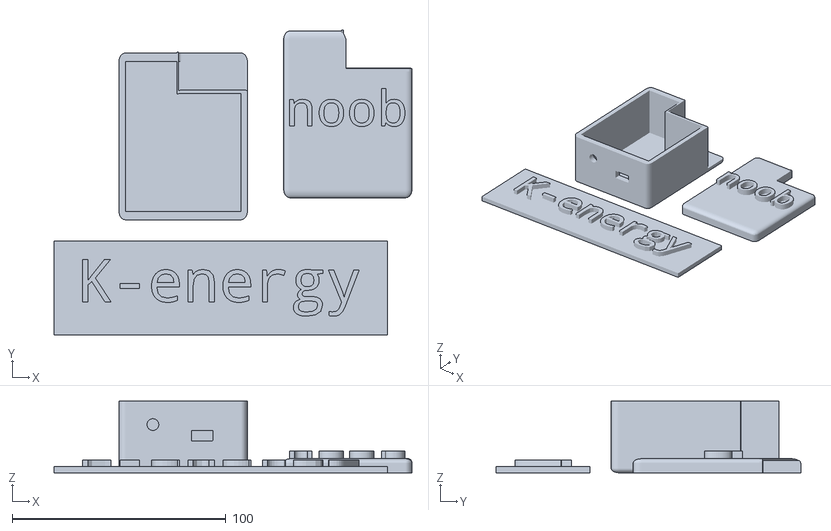
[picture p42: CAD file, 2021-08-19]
Hardware 3D file/3d 모델링 최신/졸작 모델링/배전반 2.stl
167.4 x 142.5 x 33.5

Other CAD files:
Hardware 3D file/스마트플러그/스마트플러그 뚜껑 최종.stp
Hardware 3D file/cover.stp
Hardware 3D file/바닥만.stl
Hardware 3D file/3d 모델링 최신/졸작 모델링/1층 천장.stl
Hardware 3D file/3d 모델링 최신/졸작 모델링/배전반 전체.stl
Hardware 3D file/3d 모델링 최신/졸작 모델링/배전반 천장.stl
Hardware 3D file/cover.3dm
Hardware 3D file/smart_plug.3dm
Hardware 3D file/바닥만.3dm
Hardware 3D file/스마트플러그 뚜껄 수정.3dm
Hardware 3D file/스마트플러그/스마트플러그 뚜껑 최종.3dm
Hardware 3D file/스마트플러그/스마트플러그 뚜껑 최종.stl
Hardware 3D file/제목없음.3dm
Hardware 3D file/허브 전체 렌더링.3dm
Hardware 3D file/허브/카메라뚜껑.3dm
Hardware 3D file/허브/카메라뚜껑.stl
Hardware 3D file/허브/허브 뚜껑.3dm
Hardware 3D file/허브/허브 뚜껑.stl
Hardware 3D file/허브/허브 몸통.3dm
Hardware 3D file/허브/허브 몸통.stl
Hardware 3D file/허브/허브다리.3dm
Hardware 3D file/허브/허브다리.stl

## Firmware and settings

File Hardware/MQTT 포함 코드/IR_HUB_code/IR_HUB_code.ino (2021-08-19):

//이 코드는 io와 ir제어를 합친 코드로 이는 아직 깃헙에는 업로드 하지 않고 테스트용 코드임
#define IO_USERNAME "whfwkr16"
#define IO_KEY "#######################"


//#define WIFI_SSID "SK_WiFiGIGA04C6_2.4G"
//#define WIFI_PASS "1803003041" //이거 바꿔

//재현이형꺼
//#define WIFI_SSID "AndroidHotspot1283"
//#define WIFI_PASS "j1234567" //이거 바꿔

//내꺼
#define WIFI_SSID "DongD"
#define WIFI_PASS "qazwsxedc" //이거 바꿔


#include "AdafruitIO_WiFi.h"

//IR관련 헤더
#include <ESP8266WiFi.h>
#include <IRremote.h>

//IR관련 핀맵설정
#define IR_RECEIVE_PIN          14 // D5
#define IR_RECEIVE_PIN_STRING   "D5"
#define IR_SEND_PIN             12 // D6 - D4/pin 2 is internal LED
#define IR_SEND_PIN_STRING      "D6"

#define DELAY_AFTER_SEND 2000
#define DELAY_AFTER_LOOP 5000




#if defined(USE_AIRLIFT) || defined(ADAFRUIT_METRO_M4_AIRLIFT_LITE) ||         \
    defined(ADAFRUIT_PYPORTAL)
// Configure the pins used for the ESP32 connection
#if !defined(SPIWIFI_SS) // if the wifi definition isnt in the board variant
// Don't change the names of these #define's! they match the variant ones
#define SPIWIFI SPI
#define SPIWIFI_SS 10 // Chip select pin
#define NINA_ACK 9    // a.k.a BUSY or READY pin
#define NINA_RESETN 6 // Reset pin
#define NINA_GPIO0 -1 // Not connected
#endif
AdafruitIO_WiFi io(IO_USERNAME, IO_KEY, WIFI_SSID, WIFI_PASS, SPIWIFI_SS,
                   NINA_ACK, NINA_RESETN, NINA_GPIO0, &SPIWIFI);
#else
AdafruitIO_WiFi io(IO_USERNAME, IO_KEY, WIFI_SSID, WIFI_PASS);
#endif

#include <typeinfo>

// set up the 'counter' feed
AdafruitIO_Feed *counter = io.feed("counter");
AdafruitIO_Feed *E421 = io.feed("E421"); //듀얼피드 확인용
void setup() {

  // start the serial connection
  Serial.begin(115200);

  // wait for serial monitor to open
  while (! Serial);

  Serial.print("Connecting to Adafruit IO");

  // connect to io.adafruit.com
  io.connect();

  // wait for a connection
  while (io.status() < AIO_CONNECTED) {
    Serial.print(".");
    delay(500);
  }

  // we are connected
  Serial.println();
  Serial.println(io.statusText());


//여기 핀맵관련인데 지울코드 지우자..
#if defined(__AVR_ATmega32U4__) || defined(SERIAL_USB) || defined(SERIAL_PORT_USBVIRTUAL)  || defined(ARDUINO_attiny3217)
  delay(4000); // To be able to connect Serial monitor after reset or power up and before first print out. Do not wait for an attached Serial Monitor!
#endif
  // Just to know which program is running on my Arduino
  Serial.println(F("START " __FILE__ " from " __DATE__ "\r\nUsing library version " VERSION_IRREMOTE));

  IrSender.begin(IR_SEND_PIN, ENABLE_LED_FEEDBACK); // Specify send pin and enable feedback LED at default feedback LED pin

  Serial.print(F("Ready to send IR signals at pin "));
#if defined(ARDUINO_ARCH_STM32) || defined(ESP8266)
  Serial.println(IR_SEND_PIN_STRING);
#else
  Serial.println(IR_SEND_PIN);
#endif

#if !defined(SEND_PWM_BY_TIMER) && !defined(USE_NO_SEND_PWM) && !defined(ESP32) // for esp32 we use PWM generation by ledcWrite() for each pin
  /*
     Print internal signal generation info
  */
  IrSender.enableIROut(38);

  Serial.print(F("Send signal mark duration is "));
  Serial.print(IrSender.periodOnTimeMicros);
  Serial.print(F(" us, pulse correction is "));
  Serial.print((uint16_t) PULSE_CORRECTION_NANOS);
  Serial.print(F(" ns, total period is "));
  Serial.print(IrSender.periodTimeMicros);
  Serial.println(F(" us"));
#endif




}

void loop() {


  io.run();


  //Serial.println(count);
  //counter->save(1000);
  Serial.println(io.statusText());

  counter->onMessage(handleMessage); //메시지 수신했음

  E421->onMessage(handleMessage); //메시지 수신했음 //여기피드도 숫자로 조져야함


  delay(5000);

}

//등록되어있는 피드의 값을 받아옴
void handleMessage(AdafruitIO_Data *data) {

  //Serial.print("received <- ");
  Serial.println(data->value());
  int state = data->toInt();
  if (state == 1) {
    Serial.println("Power On"); //켜졌을때
    Serial.println(F("Send NEC"));
    Serial.flush();
    //잘 모르겠는데 옛날 함수가 잘먹어
    IrSender.sendNEC(0xC1AA59A6,32);
  }
  if (state == 0) {
    Serial.println("Power OFF"); //켜졌을때
    IrSender.sendNEC(0xC1AA4DB2,32);
  }
  if (state == 11) {
    Serial.println("Radio ON"); //421켜졌을때
    IrSender.sendNEC(0xFFA25D,32);
  }
  if (state == 12) {
    Serial.println("Radio OFF"); //421켜졌을때
    IrSender.sendNEC(0xFFA25D,32);
  }

}

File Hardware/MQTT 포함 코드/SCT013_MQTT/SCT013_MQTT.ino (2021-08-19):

#include <ESP8266WiFi.h>
#include <PubSubClient.h>
char ssid[] = "DongD";           // your network SSID (name)
char pass[] = "qazwsxedc";           // your network password
const char* mqtt_server = "elijah.iptime.org"; // your MQTT broker,  MQTT브로커 기기가 연결된 IP주소, 숫자사이가 마침표 임 (쉼표아님)
WiFiClient esp8266Client;
PubSubClient client(esp8266Client);

char msg[50];
int value = 0;


//내꺼
#define WIFI_SSID "DongD"
#define WIFI_PASS "qazwsxedc" //이거 바꿔


#include "EmonLib.h"
// Include Emon Library
EnergyMonitor emon1;
// Create an instance


double total_power = 0; //누적전력
double power = 0;

#include <ESP8266WiFi.h> //와이파이
//mysql 연결관련 헤더
#include <MySQL_Connection.h>
#include <MySQL_Cursor.h>

//시간 관련 헤더
#include <DateTime.h>
#include <ESPDateTime.h>
#include <TimeElapsed.h>

//sql 연결셋팅부
IPAddress server_addr(13, 209, 100, 19); // IP of the MySQL *server* here
char hostname[] = "database-1.cshxrgoa1y2b.ap-northeast-2.rds.amazonaws.com";
char user[] = "kdh";
char password_[] = "kim";        // MySQL user login password


MySQL_Connection conn(&esp8266Client);
MySQL_Cursor* cursor;

char INSERT_SQL[] = "INSERT INTO test_arduino.hello_arduino (message) VALUES ('Hello, Arduino!')"; //샘플쿼리;
char UPDATE_SQL[] = "INSERT INTO test_arduino.hello_arduino (message) VALUES ('Hello, Arduino!')"; //샘플쿼리;
char Time_now[] = "0000-00-00 00:00:00"; //datetime 형태

//반복을 피하기 위한 변수
int now_min = 99;


void Wifi_connect() {

  Serial.println("---------------------------------------");
  Serial.println(WIFI_SSID);
  WiFi.begin(WIFI_SSID, WIFI_PASS); // 와이파이 이름과 비밀번호를 통해 WIFI연결을 시작 // WL_CONNECTED라는 값을 돌려준다
  while (WiFi.status() != WL_CONNECTED) {
    // 네트워크의 연결 상태, 8개의 리턴값
    // STATUS와 WL_CONNECTED 값이 같은지를 통해 제대로 연결이 되있는지를 확인할 수 있다
    delay(500);
    Serial.print(".");
  }

  Serial.println();
  Serial.println("Wifi connected!");
  Serial.println("\nConnected to network");
  Serial.print("My IP address is: ");
  Serial.println(WiFi.localIP());
}

void setup()
{
  Serial.begin(115200);

  //sql관련
  Wifi_connect(); //와이파이 연결


  emon1.current(A0, 50);             // Current: input pin, calibration.

  setupDateTime();//시간설정

  Serial.print("Connecting to SQL...  ");
  if (conn.connect(server_addr, 3306, user, password_)) {
    Serial.println("OK.");
  }
  else {
    Serial.println("FAILED.");
  }
  // create MySQL cursor object
  cursor = new MySQL_Cursor(&conn);

  client.setServer(mqtt_server, 1883);
  client.setCallback(callback);
  delay(500);
  client.subscribe("Test");  //MQTT 토픽
}

void loop()
{
  if (!client.connected()) {
    reconnect();
    client.subscribe("Test");
    delay(500);
  }
  client.loop();
  double Irms = emon1.calcIrms(1480);  // Calculate Irms only

  Serial.print("사용전력 : ");
  Serial.println(Irms * 220.0);         // Apparent power
  power = Irms * 220.0;
  Serial.print("현재 전류 : ");
  Serial.println(Irms);             // Irms

  total_power += power * 1 / 36000;
  delay(1000); //adafruit에는 2초에 하나 보내야 스로틀이 안걸림 따라서 이 코드 두번 조져야 함.

  Irms = emon1.calcIrms(1480);  // Calculate Irms only
  Serial.print("사용전력 : ");
  Serial.println(Irms * 230.0);         // Apparent power
  power = Irms * 230.0;
  Serial.print("현재 전류 : ");
  Serial.println(Irms);             // Irms

  total_power += power * 1 / 36000;

  delay(1000);

  snprintf (msg, 75, "%d", int(power));
  Serial.print("Publish message: ");
  Serial.println(msg);
  client.publish("SCT013", msg);

  Serial.print("누적전력사용량 : ");
  Serial.println(total_power);             // Irms
  //

  //5분마다 누적전력을 박아줄꺼야 단위는 kW
  DateTimeParts p = DateTime.getParts();


  if (now_min != p.getMinutes()) {
    if (p.getMinutes() % 5 == 0) { //여기가 5분단위 시점 5분마다 0초에

      now_min = p.getMinutes(); //현재의 분을 다시 넣어
      Serial.println(now_min);

      //Serial.println(DateTime.toString()); //5분단위 시간 확인
      sprintf(Time_now, "%04d-%02d-%02d %02d:%02d:00", p.getYear(),
              p.getMonth() + 1, p.getMonthDay(), p.getHours(), p.getMinutes()); //datetime형태로 저장

      Serial.printf("%s", Time_now); //저장된 시간 확인 00초

      sprintf(INSERT_SQL, "INSERT INTO db.Hub (datetime,store_id,amp) VALUES ('%s',11,%f)", Time_now , total_power); //시간만 일단 넣자. 오류가 뜨면 있는거니까 상관없고 안들어가있으면 데이터 들어갈공간 만들어주는거니까
      Serial.println(INSERT_SQL);

      snprintf (msg, 75, "%d", int(total_power));
      Serial.print("Publish message: ");
      Serial.println(msg);
      client.publish("Total_power", msg);
      total_power = 0;
      if (conn.connected()) {
        Serial.println("query go");
        cursor->execute(INSERT_SQL); //쿼리 돌렸어요~
      }


    }
  }
}

void callback(char* topic, byte* payload, unsigned int length) {
  Serial.print("Message arrived [");
  Serial.print(topic);
  Serial.print("] ");
  String Message = "";
  int i = 0;
  while (i < length) Message += (char)payload [i++];
  Serial.println (Message);

  if (Message == "1" ) { //MQTT 토픽 Switch1에 1이 수신되면 릴레이를 켬
    client.publish("Test_status", "received TURN ON");
    // your codes for turn on relay
    Serial.println("스위치 On");
    //digitalWrite(15,HIGH);
  }
  if (Message == "0" ) { //MQTT 토픽 Switch1에 0이 수신되면 릴레이응 끔
    client.publish("Test_status", "received TURN OFF");
    // your codes for turn off relay
    Serial.println("스위치 Off");
    //digitalWrite(15,LOW);
  }
}

void reconnect() {
  while (WiFi.status() != WL_CONNECTED) {
    delay(500);
    Serial.print(".");
    Wifi_connect();
  }
  while (!client.connected()) {
    Serial.println("Attempting MQTT connection...");
    if (client.connect("arduinoClientRelay")) {     //MQTT client name 고유한 이름으로 중복되지 않도록 주의
      Serial.println("connected");
    }
    else {
      Serial.print("MQTT connection failed, retry count: ");
      Serial.println(client.state());
      Serial.println("try again in 3 seconds");
      delay(3000);
    }
  }
}



void setupDateTime() {
  // 와이파이 연결이후에 수정하세요
  // you can use custom timeZone,server and timeout
  DateTime.setTimeZone("UTC-9");
  //DateTime.setServer("asia.pool.ntp.org");
  DateTime.begin(15 * 1000);
  //DateTime.setTimeZone(9);
  DateTime.begin();
  if (!DateTime.isTimeValid()) {
    Serial.println("Failed to get time from server.");
  }
}

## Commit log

2021-01-16 머신러닝 코드
    [climate-energy.csv, international-airline-passengers.csv]
2021-01-16 Update DHT_Wifi_Sql_control.ino
    but 전류센서 오류
2021-01-16 Update DHT_Wifi_Sql_control.ino
    전류측정코드 바꿈
2021-01-17 머신러닝 코드
    새로운 머신 러닝 모델 추가
    임의의 데이터로 예측값 출력
2021-01-18 전류센서 셋팅 완료
2021-01-18 AMP_test 일단 최종
2021-01-19 스프링 프레임워크
    스프링 프레임 워크 베이스 기본 구조 공부
2021-01-20 전류측정 최종본
    getVPP함수 추가
    기존 교류전류측정에있어 최댓값 최솟값 뽑아냄
    측정결과 led스탠드 약 100mA
    드라이기 1A수준
2021-01-22 Create springBase02.zip
    스프링 프레임 워크 베이스
2021-01-23 Create springBase03.zip
    DB와 스프링 연결
    DB에 저장된 데이터 값 옮겨서 출력
2021-01-24 sensor_query_complete
    시간별로 쿼리전송가능
    인터넷연결 끊어질시 재접속
2021-01-27 Create PPT 모핑 효과 테스트.pptx
    Office365 아닌 사람 중에, 해당 기능이 일반 파워포인트 버전과 호환 가능한지 확인 부탁함
2021-01-28 Create TestSpring.zip
    - 이름을 TestSpring으로 변경
    - index 안 거치고 바로 test1.jsp로 가도록 변경
    - datetime 초 단위 버리고 출력
    - 기존 데이터에 env 조인해서 출력
2021-02-05 Create mySystem08.ipynb
    - DB 데이터 파이썬에서 데이터 프레임으로 뽑기
    - 뽑은 데이터 머신러닝
2021-02-06 Create 2021학년도+융합·연계형+캡스톤디자인+모집+안내문_게시용 (1).hwp
2021-02-06 Create ㄴㄷㄹㄷㄴㄹ
2021-02-14 3d랜더링
    [cover.3dm, cover.stp, smart_plug.3dm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]
2021-02-27 smartplug-almost done
    디비접속이 이상함 보드문제같읔ㅁ
2021-03-01 이클립스
    이클립스 깃헙 연동
2021-03-01 Create 종합 설계 2차 발표_기업수정.pptx
2021-03-26 파일정리
2021-03-26 create readme
    오후 9:26 2021-03-26
    현재 스마트 플러그 완성된 상태이며 , 웹서버와의 연동만 이루어지면 됨.
    배전반 허브의 경우 현재 IR송수신 가능하며 라즈베리파이와의 연동 실험중
    소스코드는 추후 추가할 예정임
2021-03-26 리모컨 테스트
2021-05-01 IR제어 성공
    전자기기 제어 성공함
    추후 adafruit IO관련 코드 추가할것
2021-05-06 합성코드
    이걸기반으로 이제 IR 제어 조지면 됨
2021-05-07 Dummy Data
    - 제빙기
    - 커피 머신
    - 커피 그라인더
    - 핫 디스펜서
    - 미니 오븐
    [CoffeeGrinder_elec.csv, CoffeeMachine_elec.csv, HotWaterDispenser_elec.csv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]
2021-06-17 Create S1-7팀장김영민팀원김동혁김재현이영채 수행 보고서.docx
2021-06-17 Update S1-7팀장김영민팀원김동혁김재현이영채 수행 보고서.docx
2021-06-20 git_modify
    필요 없는 파일 삭제
    [climate-energy.csv]
2021-06-21 전류데이터 옮김
    [CoffeeGrinder_elec.csv, CoffeeMachine_elec.csv, HotWaterDispenser_elec.csv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]
2021-06-22 정리
    led strip 아두이노 파일에 넣고
    라즈베리파이 폴더 생성 후 모션인식 파일 추가
2021-06-22 ㅇㅇㅇㅇ
2021-06-22 미안하다 동혁아....
2021-06-23 Smart_Energy_Manager apk file
    웹 앱 apk 파일
2021-06-23 ver2
    ver1에서 완전 개편
2021-06-24 종합설계1 수행보고서
2021-06-24 종합설계 수행보고서
2021-06-24 종합설계1
2021-06-24 폴더를 만들어 다시 업로드
2021-06-28 Create 출처
2021-07-12 Update Light_Control.ino
    라즈베리파이 MQTT 서버 이용
2021-07-13 얼굴인식 MQTT + Adafruit 버전 저장
2021-07-13 Electricity Data
    [Airconditioner_elec.csv, Beverage_Refrigerator_elec.csv, Light_elec.csv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]
2021-07-26 folder make
    [cover.3dm, cover.stp, international-airline-passengers.csv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]
2021-08-01 Flutter App
    플러터 앱 및 앱 db 연결
2021-08-01 Flutter App change setting
    db 및 세부 설정 변경
2021-08-02 flutter_db_connect2
    db 연결 설정
2021-08-04 flutter_db_connect
    db List 데이터 출력 추가
2021-08-05 flutter_db_connect
    db로 받아온 데이터 리스트로 출력
2021-08-14 Flutter App chart
    flutter chart 출력 부분 구현
2021-08-14 HW code upload
    .
    [1층 바닥.stl, 1층 천장.stl, 2층 카메라.stl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]
2021-08-16 flutter App
    플러터 앱 정리 후 클린 적용 상태
2021-08-23 mqtt Connect
    flutter - mqtt 연결 설정
2021-08-29 data-sample-connect
    다수 채널 연결 시도
2021-08-29 connect2
    연결 재시도
2021-08-30 chart connect
    chart connect 시도
2021-09-04 flutter chart connect
    차트 json 연결
2021-09-08 flutter auto-control2
    다중 제어 출력 기능 구현
2021-09-10 Flutter App Project
    최종 오류 수정, apk 파일
2021-09-14 Revert "Create Face_MQTT_LED.py"
    This reverts commit a685d0f09c40a179e9ec1b3f4594276f9a90fdeb.
    [Face_MQTT_LED.py]
2021-09-17 flutter app push alarm
    최종본
2021-11-06 flutter app
    수정 최종
2021-12-22 Create 졸업논문 S1-7 (김영민, 김재현, 김동혁, 이영채).hwp
2021-12-22 Create 수행보고서 S1-7 - 최종 (김영민, 김동혁, 김재현, 이영채) .docx
2021-12-22 Create S1-7 최종 발표.pptx
